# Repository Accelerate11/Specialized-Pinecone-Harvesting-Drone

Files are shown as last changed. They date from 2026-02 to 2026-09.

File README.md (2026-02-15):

# Specialized-Pinecone-Harvesting-Drone

To address the issues of high safety risks and low efficiency associated with manual pinecone harvesting, as well as the significant damage and loss caused by vibratory harvesters, this project has developed an intelligent pinecone harvesting system that deeply integrates a UAV, a robotic arm, and a striking end-effector.

The system employs a coaxial oct-rotor platform to achieve maneuverable flight within forest environments. It establishes a pinecone recognition system for precise target positioning and proposes a path planning method that simultaneously considers attitude, position, and obstacles, ensuring a safe and efficient approach to the pinecones. Additionally, an integrated cooperative control dynamic model for the UAV and the robotic arm is established to enhance operational stability.

This system enables rapid identification, precise harvesting, and stable flight in complex forest environments. It effectively reduces labor costs, improves harvesting efficiency, minimizes fruit loss, alleviates labor intensity, mitigates operational risks, and contributes to the modernization of forestry.

This project selects the NVIDIA Jetson Orin Nano as the onboard computer, the CUAV X7 as the flight controller, the DJI Mid-360 as the LiDAR, the SIYI A8 mini as the gimbal camera, and an RGB-D Sensor Camera（https://wiki.dfrobot.com.cn/_SKU_SEN0583_RGB-D_Sensor_Camera） as the depth camera.

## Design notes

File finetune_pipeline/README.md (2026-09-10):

# LocateAnything 松果微调

供以后换入高质量 YOLO 数据集后复用。训练在 Win11 的 WSL2 `ld666` 中进行，不能直接拿 GGUF 训练。

## 固定环境

- Eagle：`/home/ld666/projects/Eagle`，commit `783f656d127ee498137b5ff52603ce36c292d317`
- Python 环境：`/home/ld666/venvs/locateanything`
- 完整基础模型：`/home/ld666/model-cache/LocateAnything-3B`
- 训练脚本：`/mnt/e/locate4b/finetune_pipeline/scripts/train_pinecone_lora.sh`
- checkpoint 建议放在：`/home/ld666/work_dirs/locateanything_pinecone/`

当前 Eagle 已应用 WSL/SDPA 兼容修改。若以后重新克隆 Eagle，在仓库根目录执行：

```bash
git apply --check /mnt/e/locate4b/finetune_pipeline/patches/eagle_wsl_sdpa.patch
git apply /mnt/e/locate4b/finetune_pipeline/patches/eagle_wsl_sdpa.patch
```

## 1. 准备数据

推荐新数据单独放置，不覆盖旧数据：

```text
E:\locate4b\dataset_hq\
  data.yaml
  images\train\
  images\val\
  labels\train\
  labels\val\
```

标注必须是 YOLO 检测格式：每行 `class x_center y_center width height`，坐标归一化到 0–1。训练前重点确认：所有可见松果尽量完整标注、框不越界、训练集和验证集不重复、空标注图片确实没有松果。

## 2. 转换为 ShareGPT JSONL

在 Windows PowerShell 中执行：

```powershell
python E:\locate4b\finetune_pipeline\scripts\convert_yolo_to_locateanything.py `
  --source E:\locate4b\dataset_hq `
  --output E:\locate4b\dataset_hq_true `
  --wsl-output-root /mnt/e/locate4b/dataset_hq_true
```

检查 `dataset_hq_true\conversion_report.json`，确认样本数、框数、类别和错误记录。训练使用自动生成的 `dataset_hq_true\recipe_train.json`。

## 3. 一步拉烟测试

每次换数据后必须先跑 1 步，确认数据、显存和保存流程正常：

```powershell
wsl.exe -d ld666 -- bash -lc 'META_PATH=/mnt/e/locate4b/dataset_hq_true/recipe_train.json OUTPUT_DIR=/home/ld666/work_dirs/locateanything_pinecone/smoke_hq MAX_STEPS=1 SAVE_STEPS=1 GRADIENT_ACC=1 bash /mnt/e/locate4b/finetune_pipeline/scripts/train_pinecone_lora.sh'
```

`OUTPUT_DIR` 必须使用新的空目录。

## 4. 正式微调

先跑 100 步小规模实验，不要在新数据上直接长时间训练：

```powershell
wsl.exe -d ld666 -- bash -lc 'META_PATH=/mnt/e/locate4b/dataset_hq_true/recipe_train.json OUTPUT_DIR=/home/ld666/work_dirs/locateanything_pinecone/lora_hq_v1 MAX_STEPS=100 SAVE_STEPS=50 bash /mnt/e/locate4b/finetune_pipeline/scripts/train_pinecone_lora.sh'
```

默认配置是 BF16、SDPA、LoRA rank 32、冻结视觉骨干和 MLP、上下文 4096。正式步数应根据新数据规模和验证结果决定，不要只看训练 loss。

## 5. 评估

基础模型和新 checkpoint 必须使用相同样本、相同 seed、相同 `slow` 解码分别评估：

```powershell
wsl.exe -d ld666 -- bash -lc 'source /home/ld666/venvs/locateanything/bin/activate && python /mnt/e/locate4b/finetune_pipeline/scripts/evaluate_pinecone.py --model /home/ld666/work_dirs/locateanything_pinecone/lora_hq_v1 --annotation /mnt/e/locate4b/dataset_hq_true/annotations/pinecone_val.jsonl --image-root /mnt/e/locate4b/dataset_hq_true/images --output /mnt/e/locate4b/results/eval_lora_hq_v1.json --limit 0 --seed 42 --generation-mode slow'
```

关注 Precision、Recall、F1、非法框数量和实际叠加图。只有验证集优于基础模型，才进入合并和部署转换。

## 6. 合并 LoRA

```powershell
wsl.exe -d ld666 -- bash -lc 'source /home/ld666/venvs/locateanything/bin/activate && python /mnt/e/locate4b/finetune_pipeline/scripts/merge_locateanything_lora.py --input /home/ld666/work_dirs/locateanything_pinecone/lora_hq_v1 --output /home/ld666/work_dirs/locateanything_pinecone/lora_hq_v1_merged'
```

输出目录必须为空。

## 7. 转为 GGUF 并量化

```bash
source /home/ld666/venvs/locateanything/bin/activate
mkdir -p /home/ld666/work_dirs/locateanything_pinecone/gguf_hq_v1

python /home/ld666/projects/llama.cpp-locateanything/convert_hf_to_gguf.py \
  /home/ld666/work_dirs/locateanything_pinecone/lora_hq_v1_merged \
  --outfile /home/ld666/work_dirs/locateanything_pinecone/gguf_hq_v1/LocateAnything-Pinecone-BF16.gguf \
  --outtype bf16

python /home/ld666/projects/llama.cpp-locateanything/convert_hf_to_gguf.py \
  /home/ld666/work_dirs/locateanything_pinecone/lora_hq_v1_merged \
  --outfile /home/ld666/work_dirs/locateanything_pinecone/gguf_hq_v1/LocateAnything-Pinecone-BF16.gguf \
  --outtype bf16 --mmproj

/home/ld666/projects/llama.cpp-locateanything/build/bin/llama-quantize \
  /home/ld666/work_dirs/locateanything_pinecone/gguf_hq_v1/LocateAnything-Pinecone-BF16.gguf \
  /home/ld666/work_dirs/locateanything_pinecone/gguf_hq_v1/LocateAnything-Pinecone-Q4_K_M.gguf \
  Q4_K_M
```

最后再用 `evaluate_gguf_pinecone.py` 对原始 Q4 和新 Q4 做同口径评估，通过后复制到 Jetson。

## 当前原型结果

固定 12 张低质量验证样本、llama.cpp Q4_K_M、`slow` 解码：原始模型 IoU@0.5 F1 为 0.7671，当前微调模型为 0.8010。该结果只证明流程可行，不能代替高质量数据上的重新评估。

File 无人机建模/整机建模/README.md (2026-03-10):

此文件夹用于储存整机建模，使用STEP格式
一代机建模比较粗糙，仅作了各个模块的大致位置与接合演示，一代机完成了实际飞行，使用多模块独立供电方式，以便于调试使用。

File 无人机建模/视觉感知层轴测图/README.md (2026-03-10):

视觉感知层包括视觉处理单元（1）、广角云台相机（2）、手眼相机（3）及激光雷达（4）。所述系统通过广角云台相机与手眼相机的双阶段协同检测获取多尺度视觉信息及环境深度信息，利用视觉处理单元进行数据处理与控制决策，并通过综合视觉控制模块实现松果目标的远距离先验引导识别与近距离成熟度辨识及打击定位，完成林间环境下的松果精准识别与采摘作业引导过程。

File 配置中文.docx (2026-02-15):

配置系统语言为中文

sudo apt install language-pack-zh-hans language-pack-gnome-zh-hans

安装完成后，再运行：

sudo update-locale LANG=zh_CN.UTF-8

然后reboot，系统语言应该就是中文了

配置中文拼音输入法

https://cloud.tencent.com/developer/article/2156923

首先

sudo apt-get update

sudo apt-get install fcitx-bin

sudo apt-get install fcitx-table

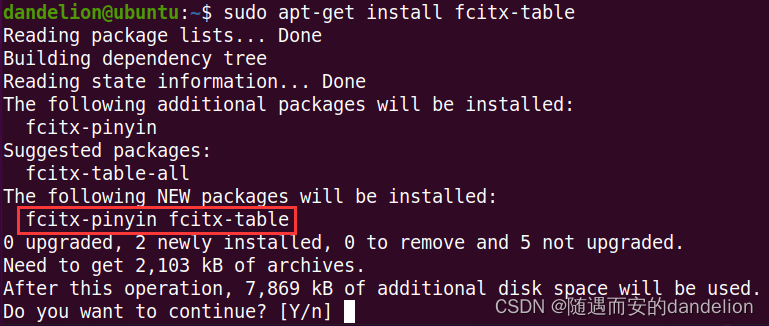
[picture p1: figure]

1、添加中文语言支持

打开 系统设置——区域和语言——管理已安装的语言——在“语言”tab下——点击“添加或删除语言”

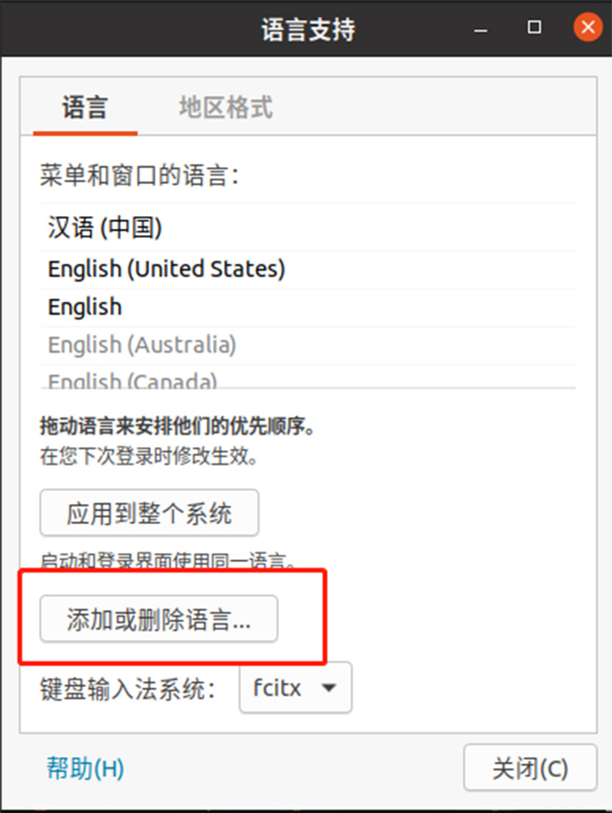
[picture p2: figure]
打开 系统设置——区域和语言——管理已安装的语言——在“语言”tab下——点击“添加或删除语言”

弹出“已安装语言”窗口，勾选中文（简体），点击应用

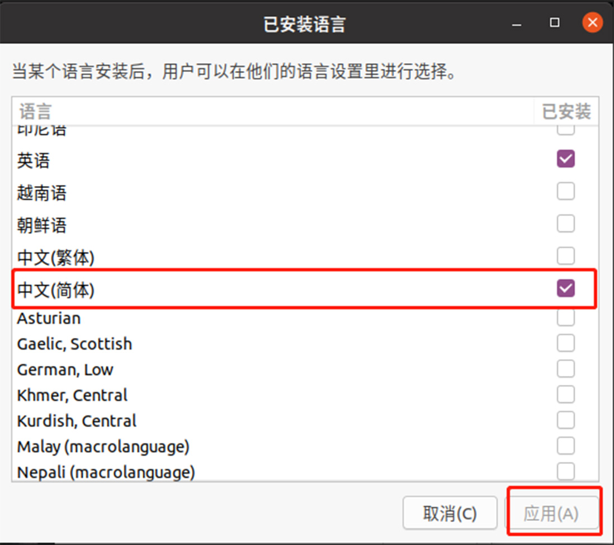
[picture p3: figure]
弹出“已安装语言”窗口，勾选中文（简体），点击应用

回到“语言支持”窗口，在键盘输入法系统中，选择“fcitx”

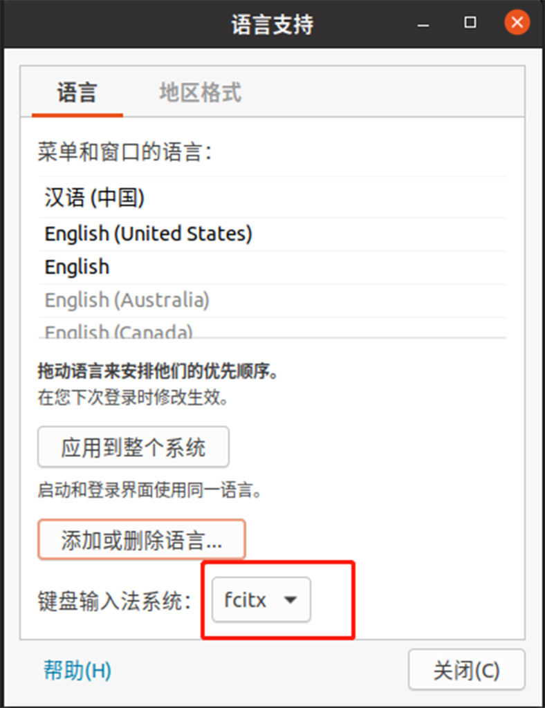
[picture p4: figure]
回到“语言支持”窗口，在键盘输入法系统中，选择“fcitx”

点击“应用到整个系统”，关闭窗口，reboot

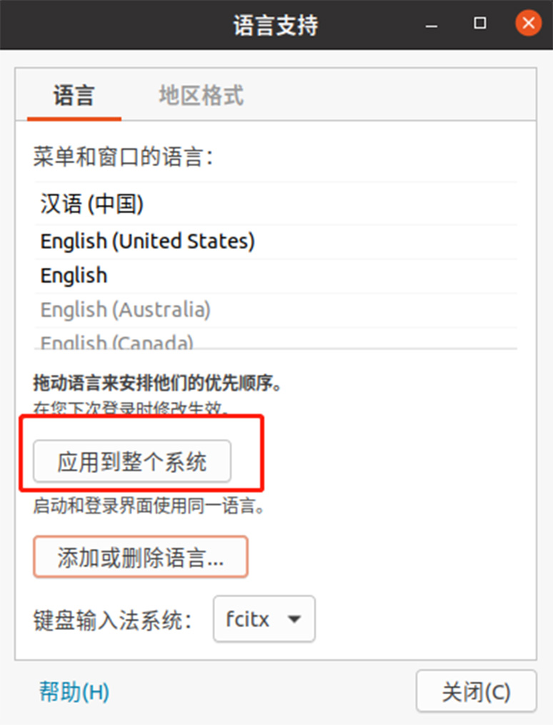
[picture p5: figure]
如果在键盘输入法系统中，没有“fcitx”选项时，建议先打开终端手动安装fcitx：sudo apt-get install fcitx等安装成功之后再执行上述步骤点击“应用到整个系统”，关闭窗口，重启电脑
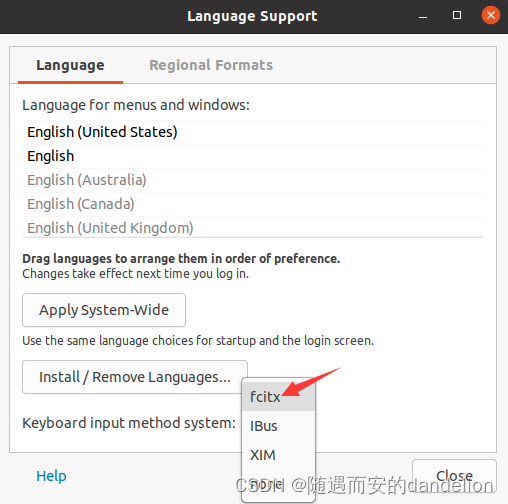
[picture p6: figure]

选择输入法框架fcitx，然后单击Close，重启系统。单击Ubuntu右上角的小键盘图标，在下拉菜单里选择Configure Current Input Method，可以看到已经安装的两个拼音输入法：

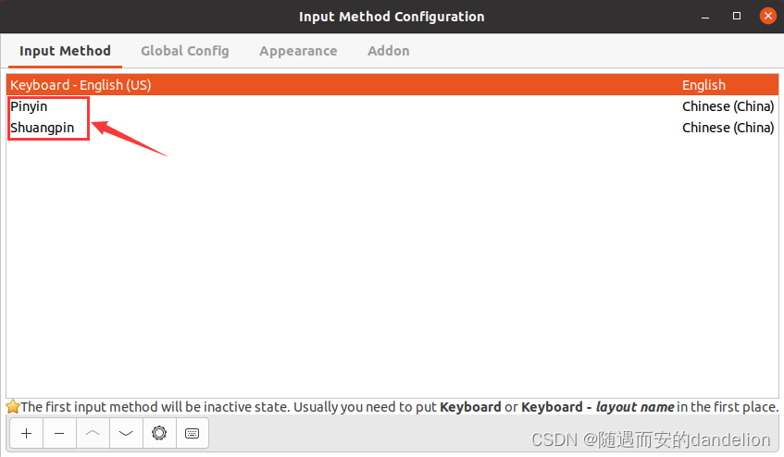
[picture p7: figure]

打开一个终端或者文本编辑器，按“CTRL+空格”键，在中文/英文输入法之间切换；按“CTRL+SHIFT”键，在fcitx框架中的多种中文输入法之间切换。

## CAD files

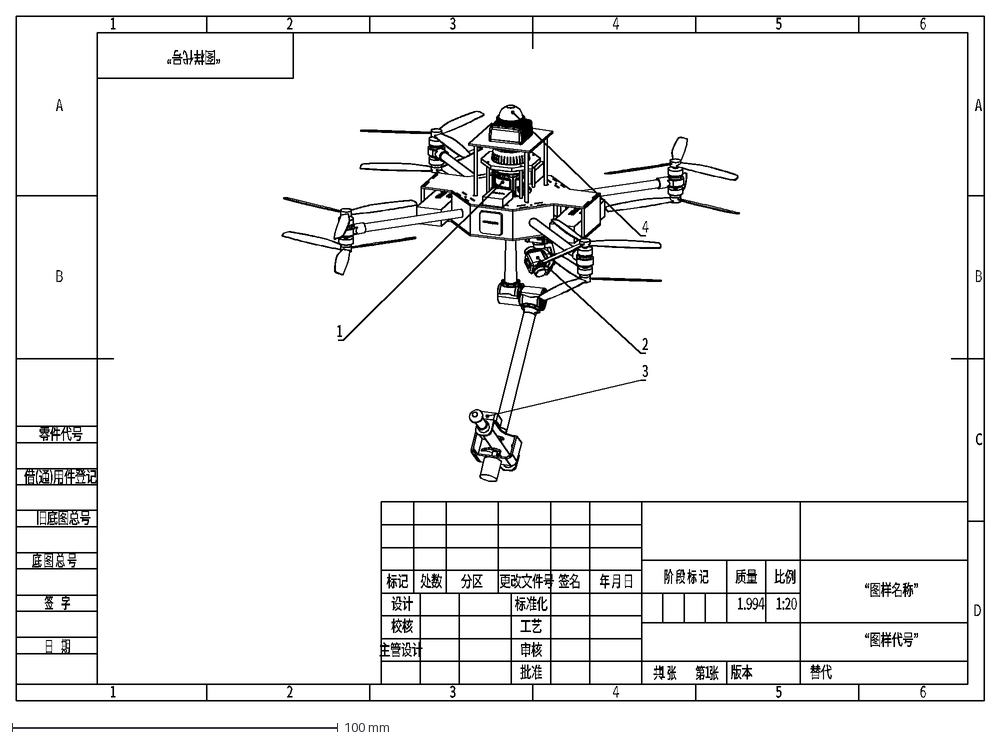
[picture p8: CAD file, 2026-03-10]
无人机建模/视觉感知层轴测图/Pick_Pinecone_Super.DXF
“图样代号”
替代
版本
审核
工艺
比例
质量
第 张
共 张
阶 段 标 记
批准
标准化
主管设计
年 月 日
签名
更改文件号
分区
处数
标记
设计
校核
零件代号
借(通)用件登记
旧底图总号
底 图 总 号
日 期
“图样名称”
1.994
1
1:20
B
A
D
C
签 字
2
5
4
3
6

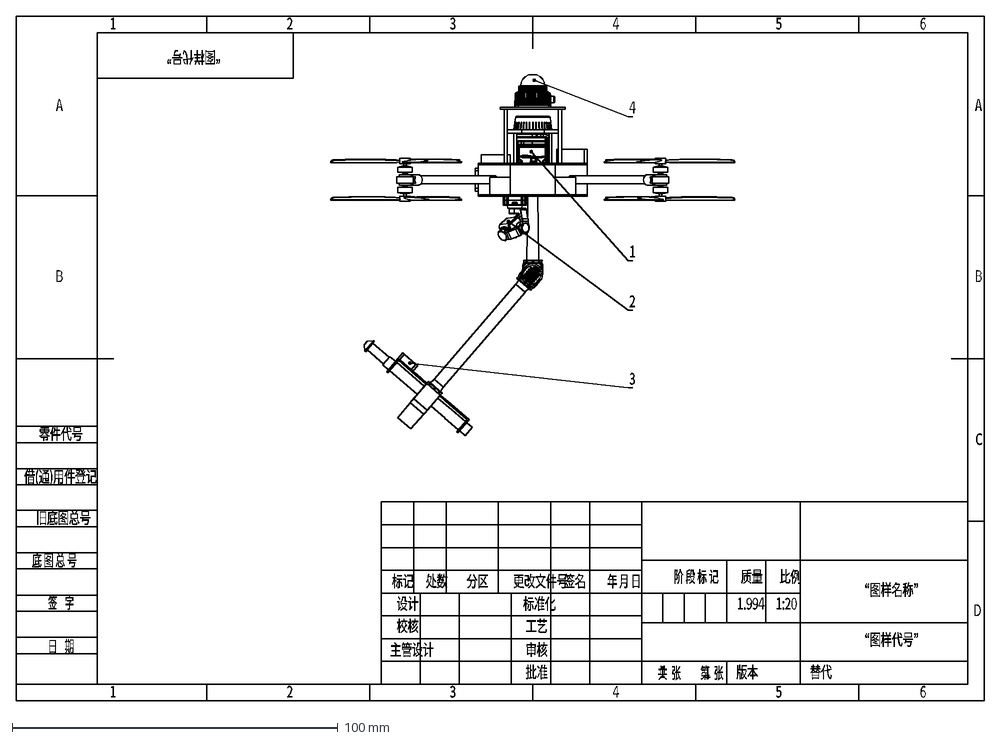
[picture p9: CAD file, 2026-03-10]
无人机建模/视觉感知层轴测图/Pick_Pinecone_Right.DXF
“图样代号”
替代
版本
审核
工艺
比例
质量
第 张
共 张
阶 段 标 记
批准
标准化
主管设计
年 月 日
签名
更改文件号
分区
处数
标记
设计
校核
零件代号
借(通)用件登记
旧底图总号
底 图 总 号
日 期
“图样名称”
1.994
1
1:20
B
A
D
C
签 字
2
5
4
3
6

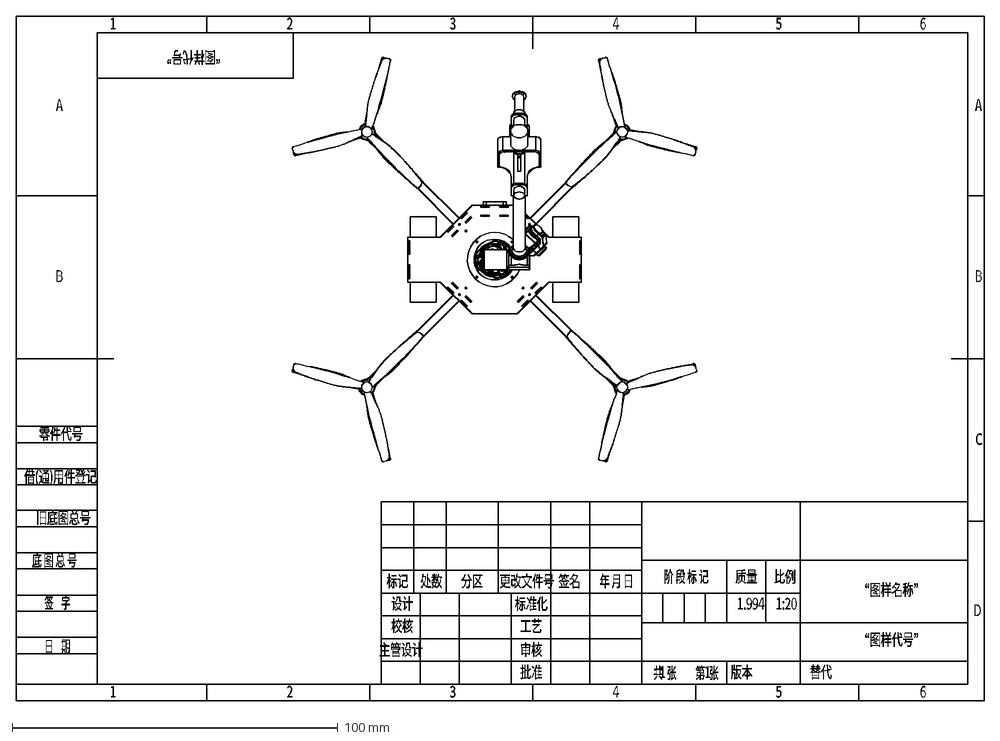
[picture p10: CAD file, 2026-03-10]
无人机建模/视觉感知层轴测图/Pick_Pinecone_Bottom.DXF
“图样代号”
替代
版本
审核
工艺
比例
质量
第 张
共 张
阶 段 标 记
批准
标准化
主管设计
年 月 日
签名
更改文件号
分区
处数
标记
设计
校核
零件代号
借(通)用件登记
旧底图总号
底 图 总 号
日 期
“图样名称”
1.994
1
1:20
B
A
D
C
签 字
2
5
4
3
6

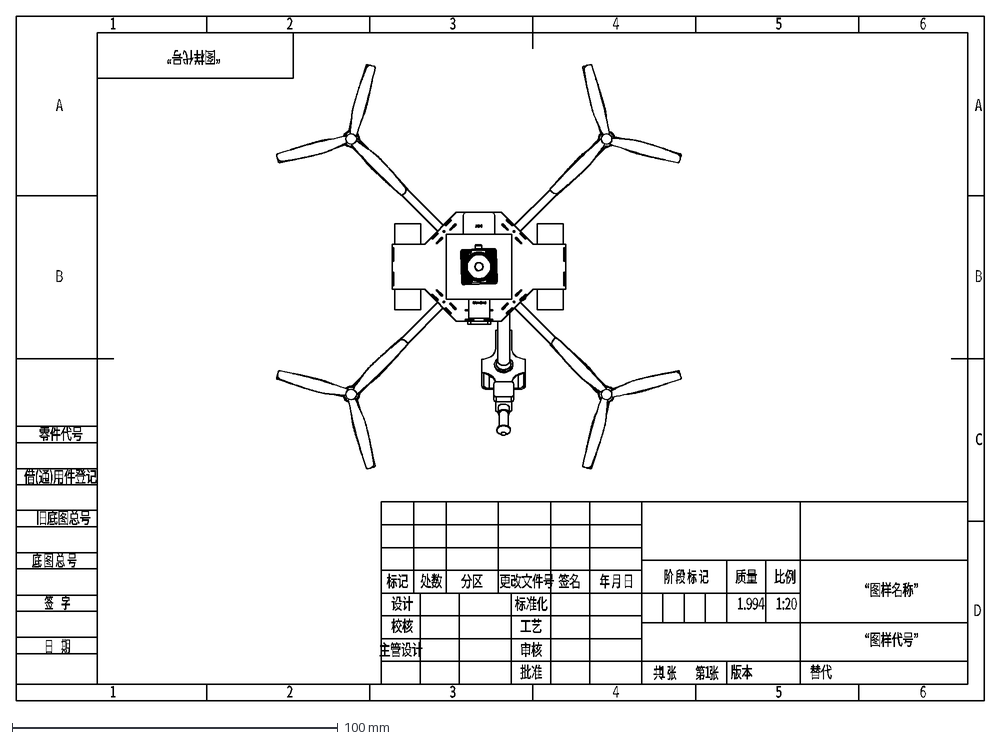
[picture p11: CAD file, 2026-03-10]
无人机建模/视觉感知层轴测图/Pick_Pinecone_Plan.DXF
“图样代号”
替代
版本
审核
工艺
比例
质量
第 张
共 张
阶 段 标 记
批准
标准化
主管设计
年 月 日
签名
更改文件号
分区
处数
标记
设计
校核
零件代号
借(通)用件登记
旧底图总号
底 图 总 号
日 期
“图样名称”
1.994
1
1:20
B
A
D
C
签 字
2
5
4
3
6

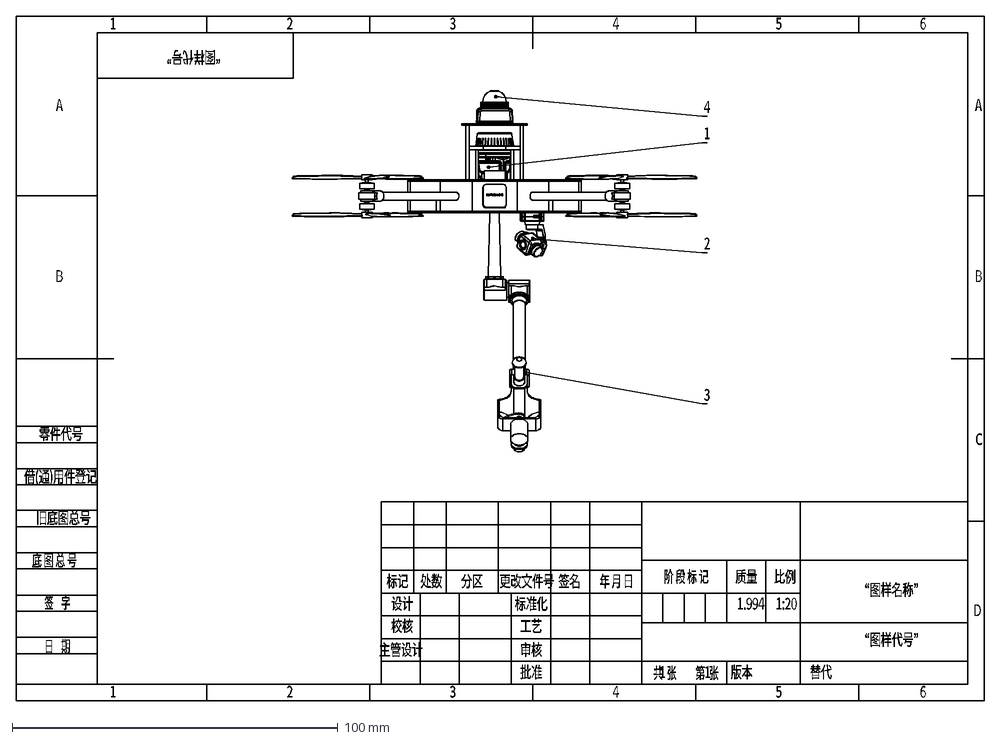
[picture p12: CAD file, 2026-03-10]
无人机建模/视觉感知层轴测图/Pick_Pinecone_Front.DXF
“图样代号”
替代
版本
审核
工艺
比例
质量
第 张
共 张
阶 段 标 记
批准
标准化
主管设计
年 月 日
签名
更改文件号
分区
处数
标记
设计
校核
零件代号
借(通)用件登记
旧底图总号
底 图 总 号
日 期
“图样名称”
1.994
1
1:20
B
A
D
C
签 字
2
5
4
3
6

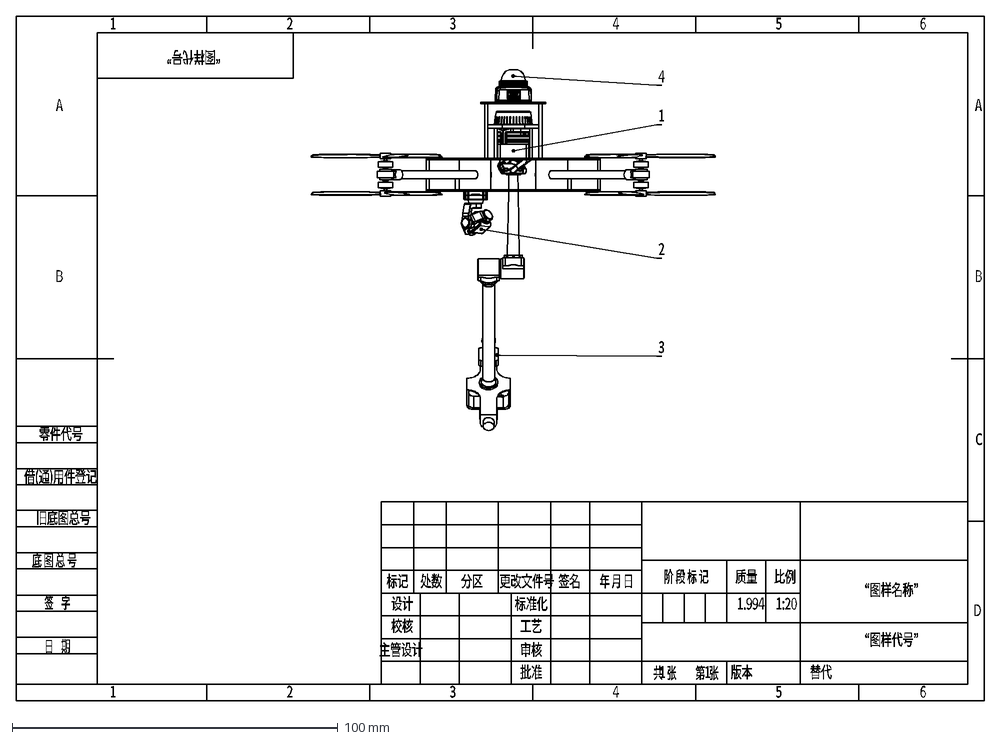
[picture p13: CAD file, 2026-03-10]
无人机建模/视觉感知层轴测图/Pick_Pinecone_Back.DXF
“图样代号”
替代
版本
审核
工艺
比例
质量
第 张
共 张
阶 段 标 记
批准
标准化
主管设计
年 月 日
签名
更改文件号
分区
处数
标记
设计
校核
零件代号
借(通)用件登记
旧底图总号
底 图 总 号
日 期
“图样名称”
1.994
1
1:20
B
A
D
C
签 字
2
5
4
3
6

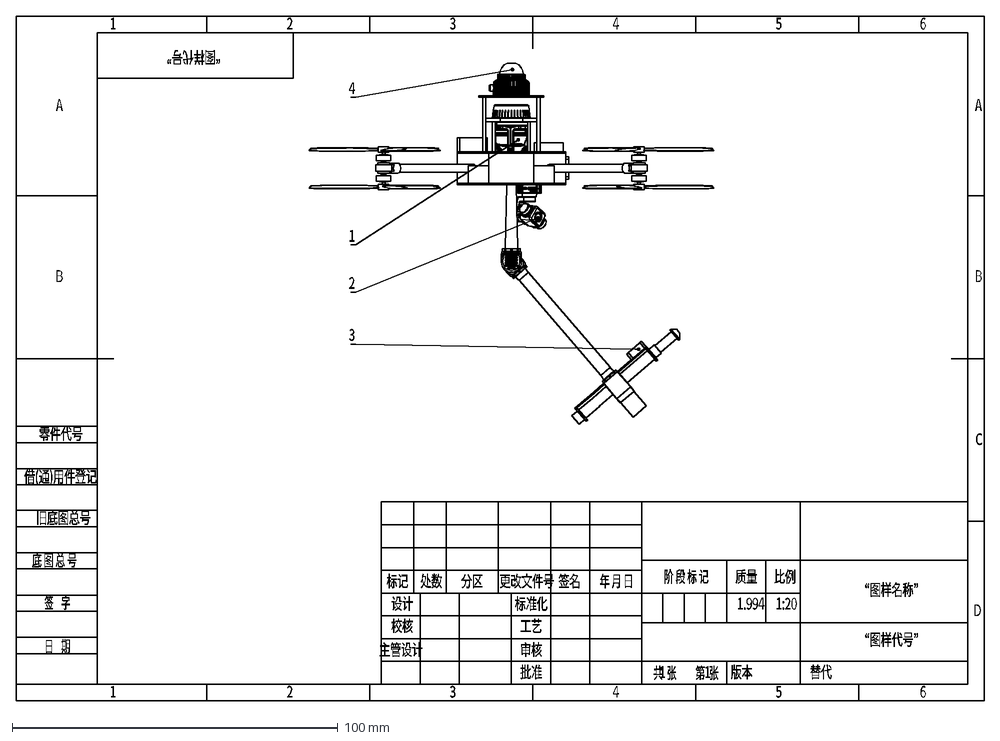
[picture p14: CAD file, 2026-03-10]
无人机建模/视觉感知层轴测图/Pick_Pinecone_Left.DXF
“图样代号”
替代
版本
审核
工艺
比例
质量
第 张
共 张
阶 段 标 记
批准
标准化
主管设计
年 月 日
签名
更改文件号
分区
处数
标记
设计
校核
零件代号
借(通)用件登记
旧底图总号
底 图 总 号
日 期
“图样名称”
1.994
1
1:20
B
A
D
C
签 字
2
5
4
3
6

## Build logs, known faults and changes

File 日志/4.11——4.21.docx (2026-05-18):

如果想实现torch模型实时推理相机视频流，请先去看配置torch的教程

建议在虚拟环境里进行以下教程，因为安装了很多包，怕污染主环境

1. 硬件连接

网线直连：用A8 mini附带的JST-GH转RJ45线连接相机，RJ45端插入Jetson Orin Nano的网口。

独立供电：用电源线给A8 mini供电（11-25.2V，3-6S电池）。同时给Jetson Orin Nano通电。

2. 软件配置

修改Jetson网络：需要将Jetson的IP设为和A8 mini同一网段，因为A8 mini出厂默认IP是192.168.144.25。

图形界面：在Ubuntu设置里为有线连接手动配置一个IP，比如192.168.144.100。

验证连接：

首先安装arp-scan

bash

sudo apt update && sudo apt install arp-scan -y

然后用arp-scan扫描当前子网，看看相机是否正常工作以及相机的IP

bash

sudo arp-scan --interface=enP8p1s0 192.168.144.0/24

预期输出

Interface: enP8p1s0, type: EN10MB, MAC: 3c:6d:66:be:bb:88, IPv4: 192.168.144.100

Starting arp-scan 1.9.7 with 256 hosts (https://github.com/royhills/arp-scan) 192.168.144.25 7c:d1:37:a8:20:22 (Unknown)

1 packets received by filter, 0 packets dropped by kernel

Ending arp-scan 1.9.7: 256 hosts scanned in 2.042 seconds (125.37 hosts/sec). 1 responded

黄色部分证明相机IP确实是192.168.144.25

获取视频流：A8 mini默认通过RTSP协议输出视频流。

先检查 RTSP 端口是否开放

bash

sudo apt install nmap -y

nmap -p 8554 192.168.144.25

预期输出

bash

Starting Nmap 7.80 ( https://nmap.org ) at 2026-04-20 21:47 CST

Nmap scan report for 192.168.144.25

Host is up (0.00037s latency).

PORT STATE SERVICE

8554/tcp open rtsp-alt

Nmap done: 1 IP address (1 host up) scanned in 0.06 seconds

使用 ffplay 测试相机是否能输出视频流

bash

sudo apt install ffmpeg -y

ffplay rtsp://192.168.144.25:8554/main.264 -fflags nobuffer -flags low_delay -framedrop

预期会输出相机实施拍摄的画面

3 python脚本（OpemCV+FFmpeg）（减少视频采集缓冲区+异步双线程 （Pipeline）降低延迟）

创建python脚本drone_inference.py

python

import cv2

import torch

import time

import argparse

import os

import threading

import queue

from pathlib import Path

from ultralytics import YOLO

class LowLatencyYOLOPipeline:

def __init__(self, model_path, video_source, width=640, height=480, fps=30):

# 优化 RTSP 传输参数：TCP、低延迟标志、减小缓冲

os.environ['OPENCV_FFMPEG_CAPTURE_OPTIONS'] = (

'rtsp_transport;tcp|max_delay;100000|buffer_size;512000|flags;low_delay'

)

# 加载模型（建议使用 TensorRT 引擎文件 .engine 以获得最低延迟）

self.model = self.load_model(model_path)

self.video_source = video_source

self.use_rtsp = isinstance(video_source, str) and video_source.startswith('rtsp://')

self.width = width

self.height = height

self.fps = fps

# 打开视频源并设置缓冲区大小为 1（关键优化）

self.cap = self._open_capture()

if not self.cap.isOpened():

raise RuntimeError(f"无法打开视频源: {video_source}")

# 读取实际参数

self.frame_width = int(self.cap.get(cv2.CAP_PROP_FRAME_WIDTH))

self.frame_height = int(self.cap.get(cv2.CAP_PROP_FRAME_HEIGHT))

self.frame_fps = self.cap.get(cv2.CAP_PROP_FPS)

print(f"视频源已开启: {self.frame_width}x{self.frame_height} @ {self.frame_fps:.2f}fps")

print(f"模型加载成功: {Path(model_path).name}")

# 异步队列：最多缓存 2 帧，丢弃旧帧以保持最低延迟

self.frame_queue = queue.Queue(maxsize=2)

self.running = True

self.reader_thread = threading.Thread(target=self._reader_worker, daemon=True)

def _open_capture(self):

"""打开视频捕获设备，强制设置缓冲区大小为 1"""

if isinstance(self.video_source, int) or (isinstance(self.video_source, str) and self.video_source.isdigit()):

source = int(self.video_source)

cap = cv2.VideoCapture(source, cv2.CAP_V4L2)

cap.set(cv2.CAP_PROP_FRAME_WIDTH, self.width)

cap.set(cv2.CAP_PROP_FRAME_HEIGHT, self.height)

cap.set(cv2.CAP_PROP_FPS, self.fps)

else:

# RTSP 或视频文件，强制使用 FFMPEG

cap = cv2.VideoCapture(self.video_source, cv2.CAP_FFMPEG)

# 关键：将缓冲区大小设为 1，避免 OpenCV 内部缓存多帧引入延迟

cap.set(cv2.CAP_PROP_BUFFERSIZE, 1)

return cap

def load_model(self, model_path):

model = YOLO(model_path)

if torch.cuda.is_available():

model.to('cuda')

return model

def _reader_worker(self):

"""生产者线程：持续读取帧，只保留最新的一帧"""

reconnect_attempts = 0

while self.running:

ret, frame = self.cap.read()

if not ret:

print("读取帧失败，尝试重新连接...")

self.cap.release()

time.sleep(1)

# 重新打开

try:

self.cap = self._open_capture()

if self.cap.isOpened():

reconnect_attempts = 0

print("重连成功")

continue

except Exception as e:

print(f"重连异常: {e}")

reconnect_attempts += 1

if reconnect_attempts > 5:

print("重连失败超过5次，退出程序")

self.running = False

break

continue

reconnect_attempts = 0 # 成功读取后重置计数

# 队列若已满，则丢弃最旧的帧（保持最新帧）

if self.frame_queue.full():

try:

self.frame_queue.get_nowait()

except queue.Empty:

pass

self.frame_queue.put(frame)

def infer_frame(self, frame):

results = self.model(frame, verbose=False)

result = results[0]

infer_time = result.speed['inference'] / 1000.0

return result, infer_time

def draw_results(self, frame, result, infer_time):

if result.boxes is not None:

for box in result.boxes:

x1, y1, x2, y2 = map(int, box.xyxy[0].tolist())

conf = float(box.conf[0])

cls_id = int(box.cls[0])

label = f"{result.names[cls_id]} {conf:.2f}"

cv2.rectangle(frame, (x1, y1), (x2, y2), (0, 255, 0), 2)

cv2.putText(frame, label, (x1, y1-10),

cv2.FONT_HERSHEY_SIMPLEX, 0.5, (0, 255, 0), 2)

fps_text = f"FPS: {1/infer_time:.1f}" if infer_time > 0 else "FPS: --"

cv2.putText(frame, fps_text, (10, 30),

cv2.FONT_HERSHEY_SIMPLEX, 1, (0, 0, 255), 2)

cv2.putText(frame, f"Infer: {infer_time*1000:.1f}ms", (10, 60),

cv2.FONT_HERSHEY_SIMPLEX, 0.7, (0, 0, 255), 2)

return frame

def run(self):

"""消费者主线程：从队列获取最新帧，进行推理并显示"""

self.reader_thread.start()

print("开始推理（低延迟模式），按 'q' 键退出...")

while self.running:

try:

# 等待新帧，超时 1 秒

frame = self.frame_queue.get(timeout=1.0)

except queue.Empty:

if not self.running:

break

continue

# 推理与绘制

result, infer_time = self.infer_frame(frame)

display_frame = self.draw_results(frame.copy(), result, infer_time)

cv2.imshow('YOLO Detection (Low Latency)', display_frame)

# 按 'q' 退出

if cv2.waitKey(1) & 0xFF == ord('q'):

self.running = False

break

# 清理资源

self.running = False

self.reader_thread.join(timeout=1.0)

self.cap.release()

cv2.destroyAllWindows()

def main():

parser = argparse.ArgumentParser(description="YOLO 推理管道")

parser.add_argument('--model', type=str, required=True, help='模型路径 (.pt 或 .engine)')

parser.add_argument('--source', type=str, default='0', help='视频源：摄像头ID、RTSP地址或视频文件')

parser.add_argument('--width', type=int, default=640, help='采集宽度')

parser.add_argument('--height', type=int, default=480, help='采集高度')

parser.add_argument('--fps', type=int, default=30, help='采集帧率')

args = parser.parse_args()

if not Path(args.model).exists():

print(f"错误：模型文件不存在 {args.model}")

return

pipeline = LowLatencyYOLOPipeline(

model_path=args.model,

video_source=args.source,

width=args.width,

height=args.height,

fps=args.fps

)

try:

pipeline.run()

except KeyboardInterrupt:

print("\n程序被用户中断")

except Exception as e:

print(f"运行时错误: {e}")

if __name__ == "__main__":

main()

运行脚本

bash

python drone_inference.py --model /home/nvidia/CAMERA/best.pt --source "rtsp://192.168.144.25:8554/main.264"

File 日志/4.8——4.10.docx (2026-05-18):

零.准备

ros2 版本 humble

给雷达供电接入电脑，设置静态ip(不要远程,建议直连)

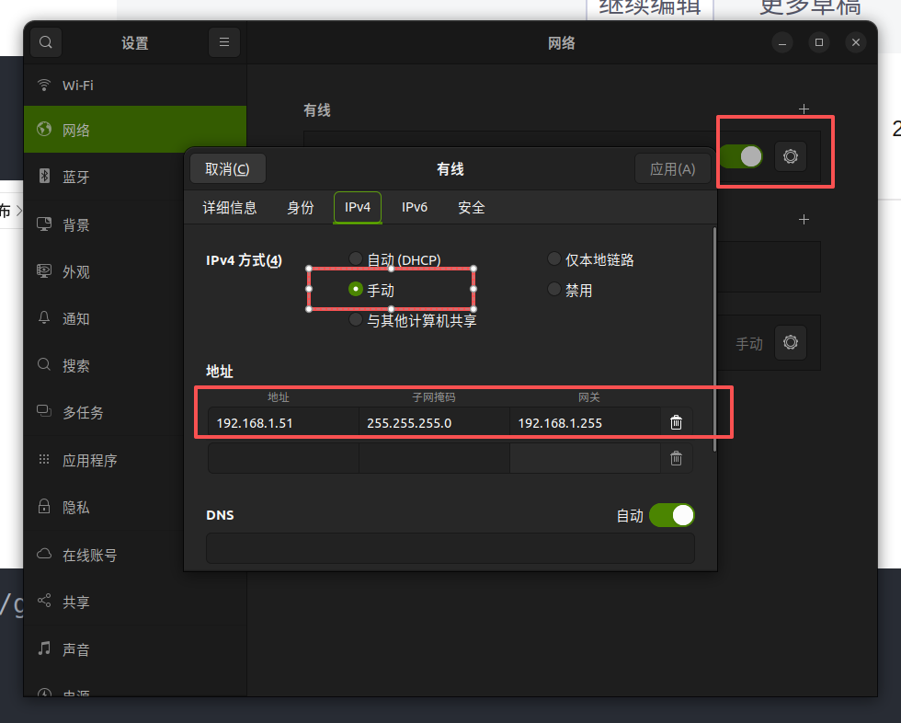
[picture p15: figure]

上述配置的IP地址是自己电脑的IP地址（记住！后面要用到）

1． sdk2

bash

git clone https://github.com/Livox-SDK/Livox-SDK2.git

cd ./Livox-SDK2/

mkdir build

cd build

cmake .. && make

sudo make install

如果linux翻墙困难的话，可以先在个人windos笔记本上通过github加速器去https://github.com/Livox-SDK/Livox-SDK2.git网址下载Livox-SDK2包（注意从网站上下载下来的源代码包自动带-master后缀，并不是你下载错了，把后缀删除了以后接着照此教程走）

2． livox_ros_driver2

bash

git clone https://github.com/Livox-SDK/livox_ros_driver2.git ws_livox/src/livox_ros_driver2

如果linux翻墙困难的话，可以先在个人windos笔记本上通过github加速器去 https://github.com/Livox-SDK/livox_ros_driver2.git网址下载Livox-ros-driver2包（注意从网站上下载下来的源代码包自动带-master后缀，并不是你下载错了，把后缀删除了以后接着照此教程走），然后创建一个名为ws_livox的文件夹，再在其中创建一个名为src的文件夹，再把源代码包放进src里

cd ws_livox/src/livox_ros_driver2

pip3 install lark

./build.sh humble

3． 修改/ws_livox/src/livox_ros_driver2/config/MID360 配置文件

参考如下

{

"lidar_summary_info" : {

"lidar_type": 8

},

"MID360": {

"lidar_net_info" : {

"cmd_data_port": 56100,

"push_msg_port": 56200,

"point_data_port": 56300,

"imu_data_port": 56400,

"log_data_port": 56500

},

"host_net_info" : {

"cmd_data_ip" : "192.168.1.51",

"cmd_data_port": 56101,

"push_msg_ip": "192.168.1.51",

"push_msg_port": 56201,

"point_data_ip": "192.168.1.51",

"point_data_port": 56301,

"imu_data_ip" : "192.168.1.51",

"imu_data_port": 56401,

"log_data_ip" : "",

"log_data_port": 56501

}

},

"lidar_configs" : [

{

"ip" : "192.168.1.141",

"pcl_data_type" : 1,

"pattern_mode" : 0,

"extrinsic_parameter" : {

"roll": 0.0,

"pitch": 0.0,

"yaw": 0.0,

"x": 0,

"y": 0,

"z": 0

}

}

]

}

上述配置文件中黄色的部分是“零.准备”中你给自己电脑配置的IP地址，红色的部分是你的激光雷达的IP地址。雷达的ip地址为192.168.1.1xx,其中的xx是贴在雷达上面的SN码的最后两位数我的是41，所以ip为192.168.1.141

四．修改动态链接库 路径

错误信息： [livox_ros_driver2_node-1] 抛出 "class_loader::LibraryLoadException" 异常 [livox_ros_driver2_node-1] 具体错误：无法加载库 dlopen 错误：liblivox_lidar_sdk_shared.so - 无法打开共享对象文件（文件不存在），位于 ./src/shared_library.c:99

bash

find ~ -name "liblivox_lidar_sdk_shared.so" 2>/dev/null

运行以上命令行找到 Livox SDK 安装位置，请确保将 SDK 文件 liblivox_lidar_sdk_shared.so 手动复制到 ~/ws_livox/install/livox_ros_driver2/lib 目录下，否则运行时会报错

五．通过rviz2查看点云

把激光雷达和你的机载电脑连接好

bash

cd ./ws_livox

colcon build

source install/setup.bash

ros2 launch livox_ros_driver2 rviz_MID360_launch.py

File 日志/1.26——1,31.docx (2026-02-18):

1.26——1.31工作总结

这一周围绕第一次真机飞行任务做了一部分适配工作，主要是写了一个云台相机录视频的脚本和一个开机自启脚本（失败）；同时，本文档补充了一些云台相机的配置说明。

云台相机供电这回使用了诱骗头，诱骗头的供电支持多种输出，方便与激光雷达和云台相机的本地调试，电压调整调整如下（后续发现诱骗头供电不稳定，上机建议使用3S航电）：

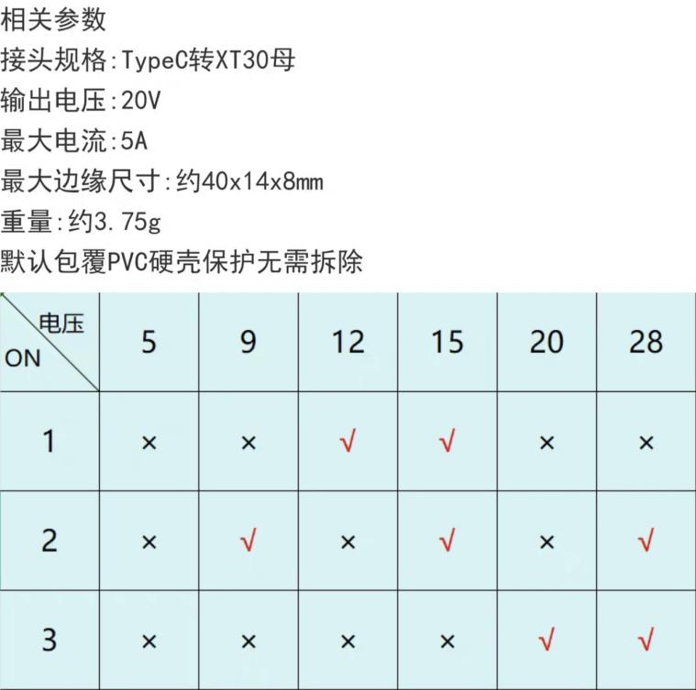
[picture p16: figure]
75cd4e96f1f75625d4e268d5966cb9c5

云台相机配置（网关配置与自检）：

1、配置Jetson OrinNano的网络

A8 mini默认IP为192.168.144.25,子网掩码255.255.255.0 (文档第4.4节)在终端中执行:

#设置静态IP(以eth0为例，请根据实际接口名称调整)

sudo ip addr add 192.168.144.30/24 dev ethe0

测试网络连通性：

ping 192.168.144.25

2、 视频流获取

安装依赖：

#安装FFmpeg

sudo apt update

sudo apt install ffmpeg

3、获取RTSP视频流

A8 mini的RTSP地址为:rtsp://192.168.144.25:8554/main.264 (文档第4.4节)

ffmpeg -i rtsp://192.168.144.25:8554/main.264 -f null -

3、 使用FFplay检查视频流是否正常：

FFplay是FFmpeg项目自带的轻量级播放器，兼容性极好。

ffplay -rtsp_transport tcp -i rtsp://192.168.144.25:8554/main.264

已经将以上步骤都集成到视频录制脚本里了

补充：清除某个旧接口的ip设置：

清空接口上的所有IP地址

此命令会移除指定接口上的所有IPv4地址。

sudo ip addr flush dev ethe

视频录制脚本部分（整理成txt放在了记录中）：

脚本源码：

!/bin/bash

# 自动网络配置与视频录制脚本

# 配置参数

CAMERA_IP="192.168.144.25" # A8 mini默认IP（文档第4.9节）

JETSON_IP="192.168.144.30" # Jetson静态IP（与相机同网段）

INTERFACE="eth0" # 网络接口名称，根据实际修改

RTSP_URL="rtsp://$CAMERA_IP:8554/main.264" # A8 mini默认RTSP地址（文档第4.4节）

OUTPUT_DIR="/home/nvidia/Videos" # 视频保存目录

# 生成带时间戳的文件名

FILENAME="a8mini_recording_$(date +%Y%m%d_%H%M%S).mp4"

OUTPUT_PATH="$OUTPUT_DIR/$FILENAME"

# 函数：记录日志

log() {

echo "[$(date '+%Y-%m-%d %H:%M:%S')] $1"

}

# 1. 检查网络接口是否存在

log "检查网络接口 $INTERFACE..."

if ! ip link show "$INTERFACE" &>/dev/null; then

log "错误: 接口 $INTERFACE 不存在。请检查接口名称（如 eth0、enp0s1）。"

exit 1

fi

# 2. 清除接口现有IP设置（避免冲突）

log "清除接口 $INTERFACE 的旧IP设置..."

sudo ip addr flush dev "$INTERFACE" 2>/dev/null

# 3. 设置静态IP

log "设置接口 $INTERFACE 的IP为 $JETSON_IP/24..."

sudo ip addr add "$JETSON_IP/24" dev "$INTERFACE"

if [ $? -ne 0 ]; then

log "警告: IP设置失败，可能已存在相同IP。尝试继续运行。"

fi

# 4. 启用接口

sudo ip link set dev "$INTERFACE" up

sleep 2 # 等待接口稳定

# 5. 验证网络连通性

log "检查相机连通性（ping $CAMERA_IP）..."

if ping -c 3 -W 3 "$CAMERA_IP" &>/dev/null; then

log "网络连通性正常。"

else

log "警告: 无法ping通相机。请检查相机供电、网线连接。"

# 不退出，尝试继续录制（可能相机需更长时间启动）

fi

# 6. 检查FFmpeg依赖

if ! command -v ffmpeg &>/dev/null; then

log "错误: FFmpeg未安装。正在尝试安装..."

sudo apt update && sudo apt install -y ffmpeg

if [ $? -ne 0 ]; then

log "错误: FFmpeg安装失败。请手动运行: sudo apt install ffmpeg"

exit 1

fi

fi

# 7. 开始录制视频

log "开始录制视频..."

log "相机RTSP流: $RTSP_URL"

log "输出文件: $OUTPUT_PATH"

log "按 Ctrl+C 停止录制。"

# 使用FFmpeg录制（-c copy 直接复制流，减少延迟）

ffmpeg -i "$RTSP_URL" -c copy -f mp4 -y "$OUTPUT_PATH"

ffmpeg_exit_code=$?

# 录制结束处理

if [ $ffmpeg_exit_code -eq 0 ]; then

log "录制已停止。视频已保存到: $OUTPUT_PATH"

elif [ $ffmpeg_exit_code -eq 255 ]; then

log "录制已被用户终止。视频已保存到: $OUTPUT_PATH"

# 检查文件是否存在且非空

if [ -s "$OUTPUT_PATH" ]; then

log "录制文件大小: $(du -h "$OUTPUT_PATH" | cut -f1)"

else

log "警告: 录制文件为空或不存在。"

fi

else

log "录制过程异常 (退出码: $ffmpeg_exit_code)。"

if [ -f "$OUTPUT_PATH" ]; then

if [ -s "$OUTPUT_PATH" ]; then

log "警告: 录制文件已保存但可能有损坏: $OUTPUT_PATH"

log "文件大小: $(du -h "$OUTPUT_PATH" | cut -f1)"

else

log "错误: 录制文件为空，正在删除..."

rm -f "$OUTPUT_PATH"

fi

fi

fi

exit $ffmpeg_exit_code

1.28同师姐去外场实际组装和测试：

云台相机测试，图像存在明显抖动，总结于云台自稳算法没有接通，并且由于我的失误未加隔振球，后续与机械臂统一再次进行测试。

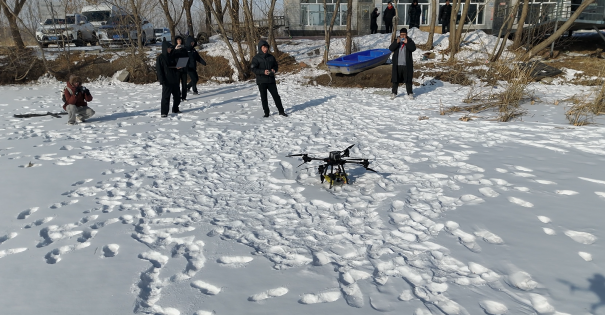
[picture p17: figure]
d642943bc4f91571ced9d0287a44630c
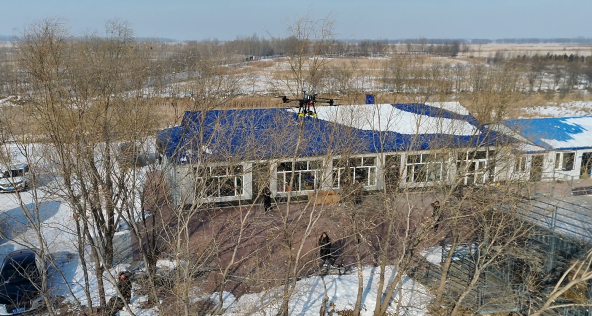
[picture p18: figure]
bdd4ffb2bf9d6f151b920efd8eb6baec
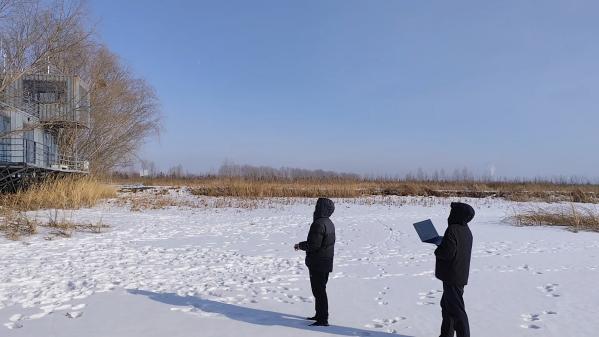
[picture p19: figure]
dfa6a3fa1fb112ef86c58c80fc97387f
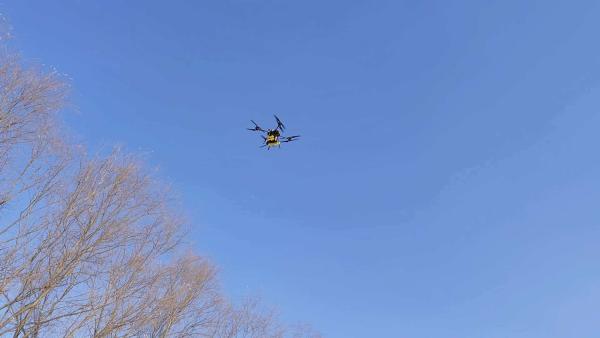
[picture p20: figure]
e085a764ea276d30c0e219d0dfdc6455

事后来到TIB与杨老师对接视觉识别算法部分，决定围绕深度相机展开视觉模型的开发；与德波学长对接过后买了两块雷巡X7+旨在给机械臂和云台各一个用来调试。固件最终确定为基于PX4。

这个周期先这样算一个小结，后续我们这边会针对飞控展开一些硬件学习和工作，主要是针对无人机的一些gazebo仿真和云台自稳的调试，明天开始本科组里面要开始美赛和离校，年前我们会分一次硬件，各个部分给相应的人去调试。

机械臂部分稳步推进，主要由倬一与王旭学长对接与调试。

本子部分馨纯参与度接近100%，主要是写挑战杯的本子，并且馨纯在视觉部分有一定的突破，等馨纯和大家返校后，会进行一次集中部署。

各个硬件尺寸和接口正在整理，很快会出。

降压模块交给李昕阳。

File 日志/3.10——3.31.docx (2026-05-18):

开学过后报名了挑战杯和国创赛，校赛都没有通过，项目目前还是存在一些问题，主要是学术产出比较少，项目商业企划不成体系，再打磨一年再去报名。

寒假期间写的专利都进入到了审核阶段。

技术层面，利用杨老师写的代码完成了YOLO数据集产出，张泽晰成功配置了基于Jetpack6.2的GPU版本pytorch环境配置并留存了详细的技术文档，清明之前可以开启视觉模型的训练。

另一方面基金会的资金到账，项目资金比较充足。

好长时间没写日志了，今天写一点吧

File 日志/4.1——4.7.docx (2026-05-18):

松果采摘机械臂由两组关节电机和两根长约为0.5m的臂杆组成，通过电机驱动二连杆将机械臂末端送至松果处进行击打。机械臂在无人机上搭载意味着需要对机械臂的震颤进行强有力的控制。而机械臂震颤来自于驱动时关节电机由于环境改变、控制指令改变、信号噪声等多种因素导致的力矩输出大幅度反复变化产生的反作用力，为了去除机械臂的震颤，本质上是要对机械臂进行柔顺控制，不能产生过大的加速度。当前阶段使用重力补偿+PID算法+滤波算法对机械臂进行柔顺控制。重力补偿是通过二连杆间的几何关系计算力矩来实时抵消机械臂运动时较明显的重力矩变化。PID算法是通过实时误差不断修正当前运动状态以达到目标运动状态，其部分代码如图所示：

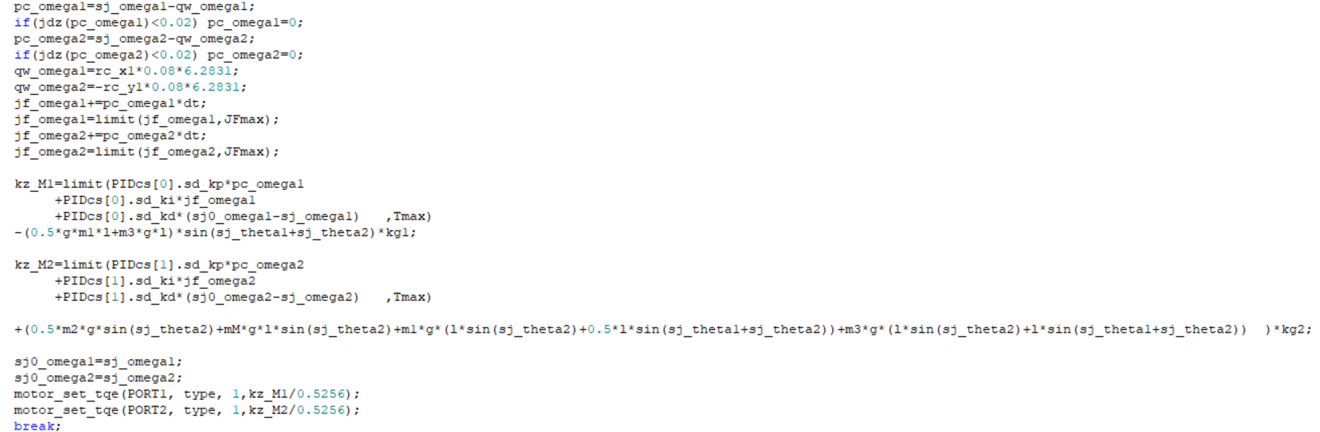
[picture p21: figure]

代码思路为：首先通过motor_get_state_send函数从电机处获取电机当前的位置（圈）、速度（圈/s）、力矩（N/m），根据电机当前位置与前一采样周期的位置之差获取电机速度，最后用电机速度结合PD参数与重力补偿控制输出力矩达到目标控制。

在程序实现过程中存在很多噪声，使得上述代码在运行时存在严重震颤。震颤产生的主要原因有：对位置进行差分时，采样周期为0.001s，电机位置的微小噪声即可产生角速度的巨大震荡，进而显著影响力矩值；电机本身读取信息时存在噪声的干扰，初始的位置信号具有一定的波动。因此滤波在此程序中十分重要，在调试过程中使用JScope可以实时观测各变量的值，相当于一台示波器，能够大大方便调试。滤波前期望速度与实际速度间的关系如图（蓝色为期望，红色为实际）

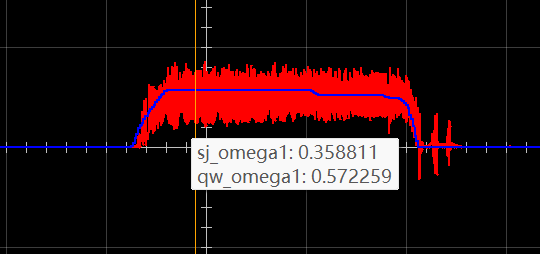
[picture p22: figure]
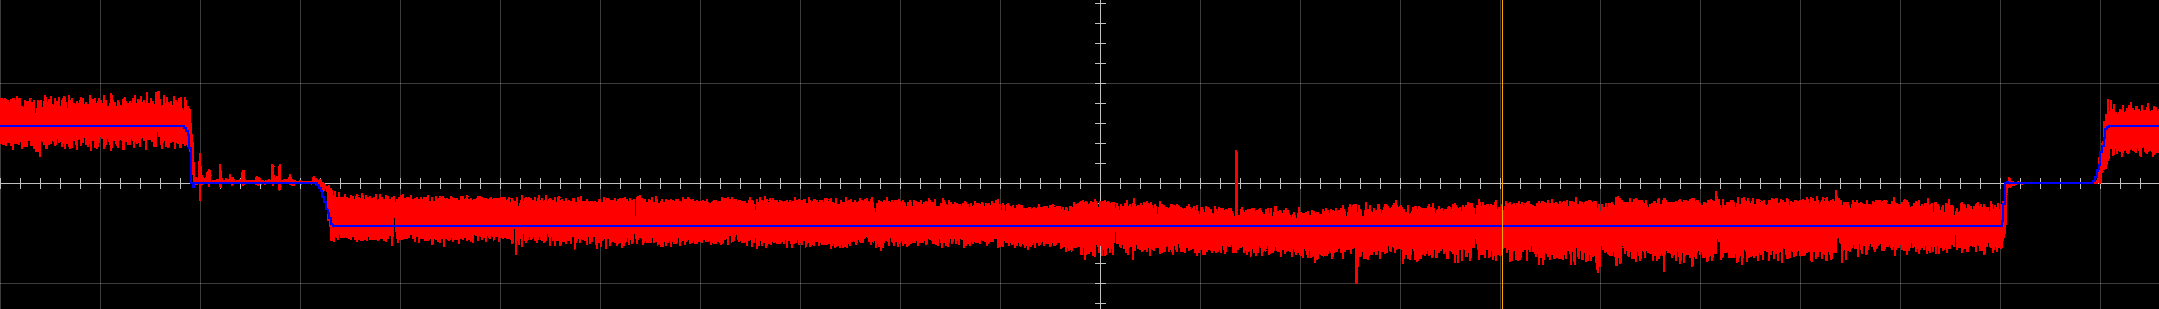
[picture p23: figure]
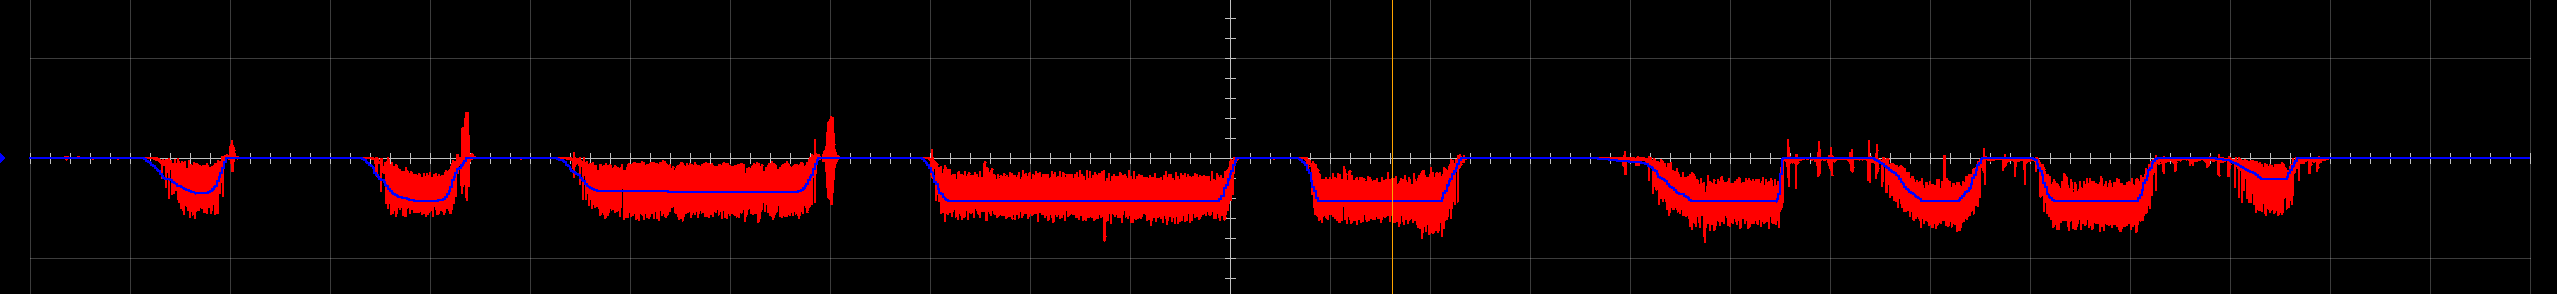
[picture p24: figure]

可见机械臂在运动过程中存在显著的高频震颤，这将对无人机的飞行产生极大威胁。

初步的滤波思路如下：通过二阶低通滤波器对位置信息进行滤波减小重力补偿精波动，通过二阶低通滤波对电机返回的速度信息进行滤波减小速度对力矩输出值的计算波动，但是试验后发现，由于对速度使用了二阶低通滤波器，滤波后的速度相位总是落后于实际速度，导致机械臂冲过头或刹过头，因此产生较大震颤（如下图所示蓝线为原始速度线，红线为过滤后的速度线）

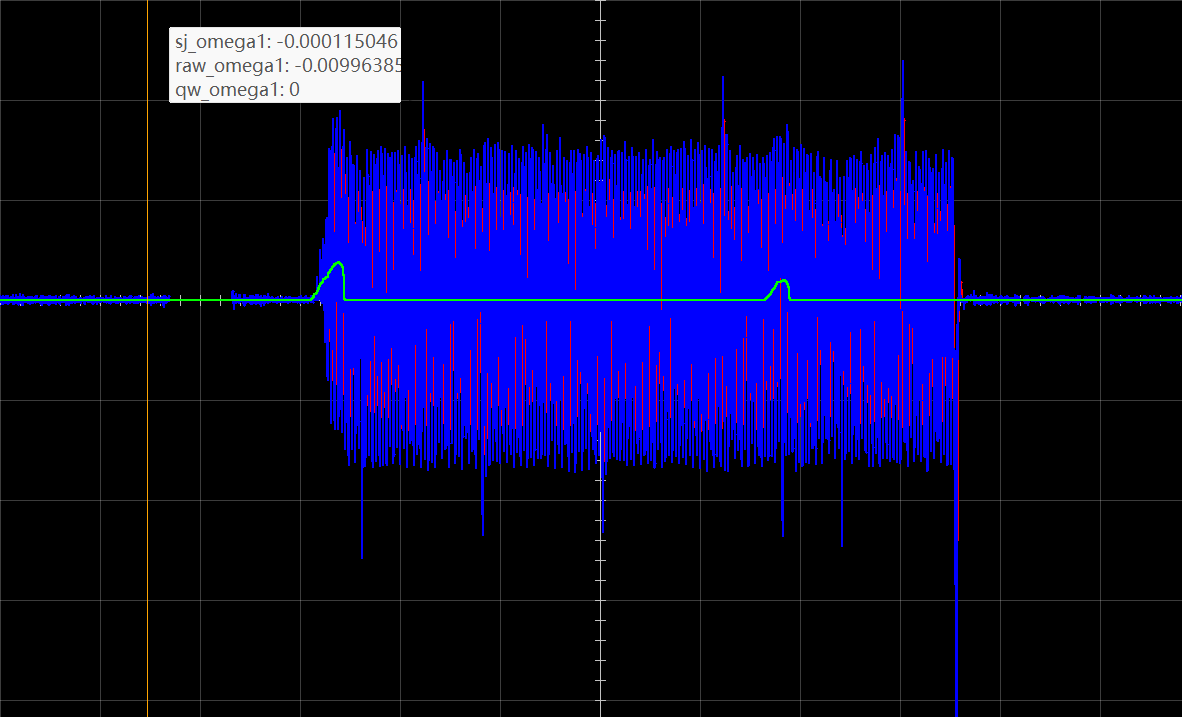
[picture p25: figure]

改进后的思路如下：通过对位置进行二阶低通滤波除去高频噪声，对位置进行差分运算得到速度，通过此速度计算力矩。由于差分dt=0.001s，差分后相当于噪声放大1000倍，极其微小的信号都能引起速度的震颤，若压低位置滤波器的截止频率则会产生相位落后过多，同样引起震颤。（如下图所示，绿线为速度线）

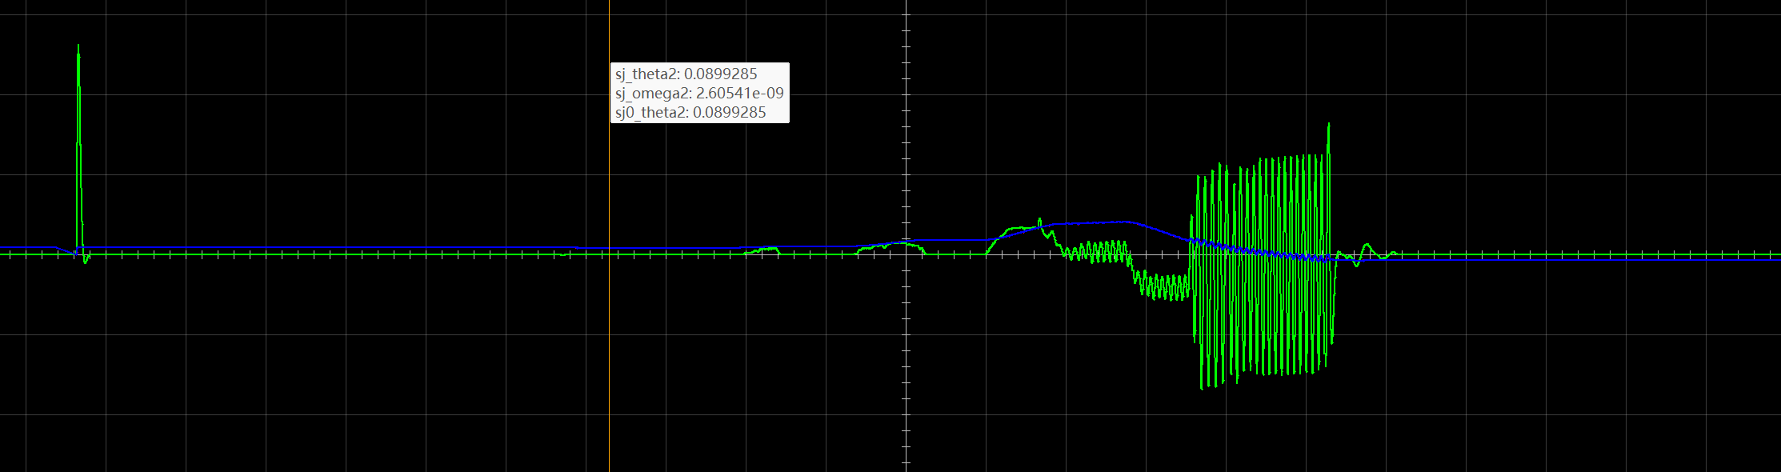
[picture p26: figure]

再次改进的思路如下：由于速度存在震颤，因此对速度再进行一次一阶低通滤波，这样可以排除二阶低通滤波落后过多相位差引起的震颤，补救差分产生的噪声。试验后发现效果并不理想，即使参数达到最优时也存在以下两个问题，第一系统在某些位置存在严重的大幅度震颤，第二系统在运行时产生了低频周期性的震颤。如下图所示（蓝线为原始值，红线为滤波后的值）：

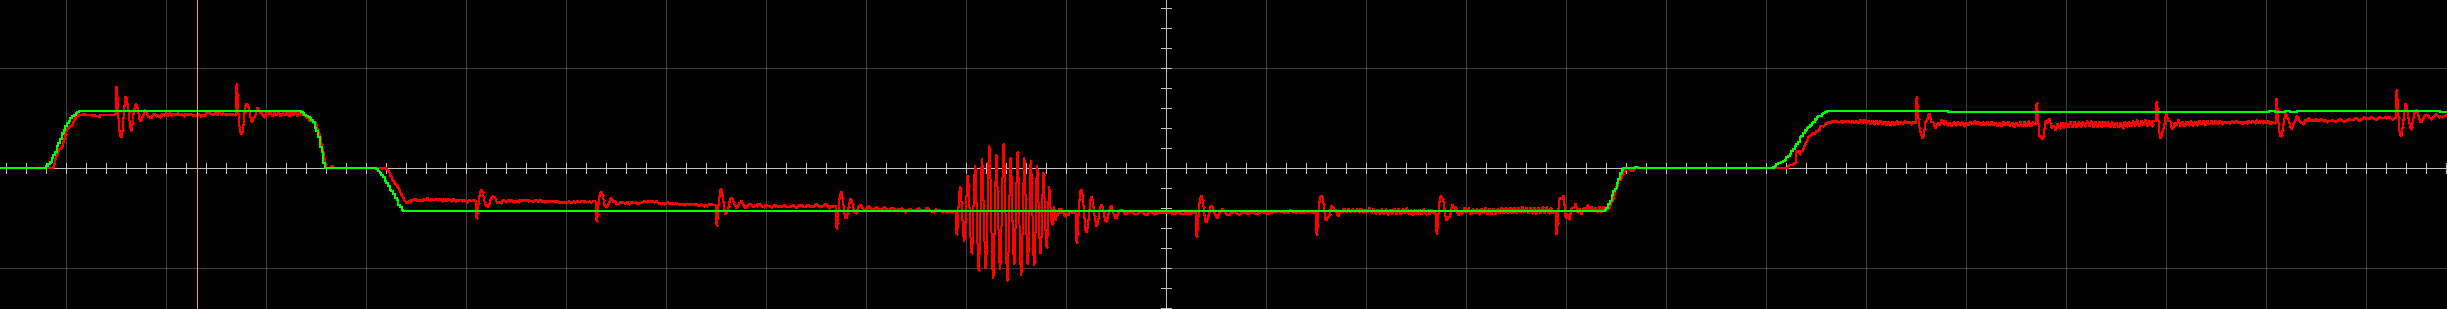
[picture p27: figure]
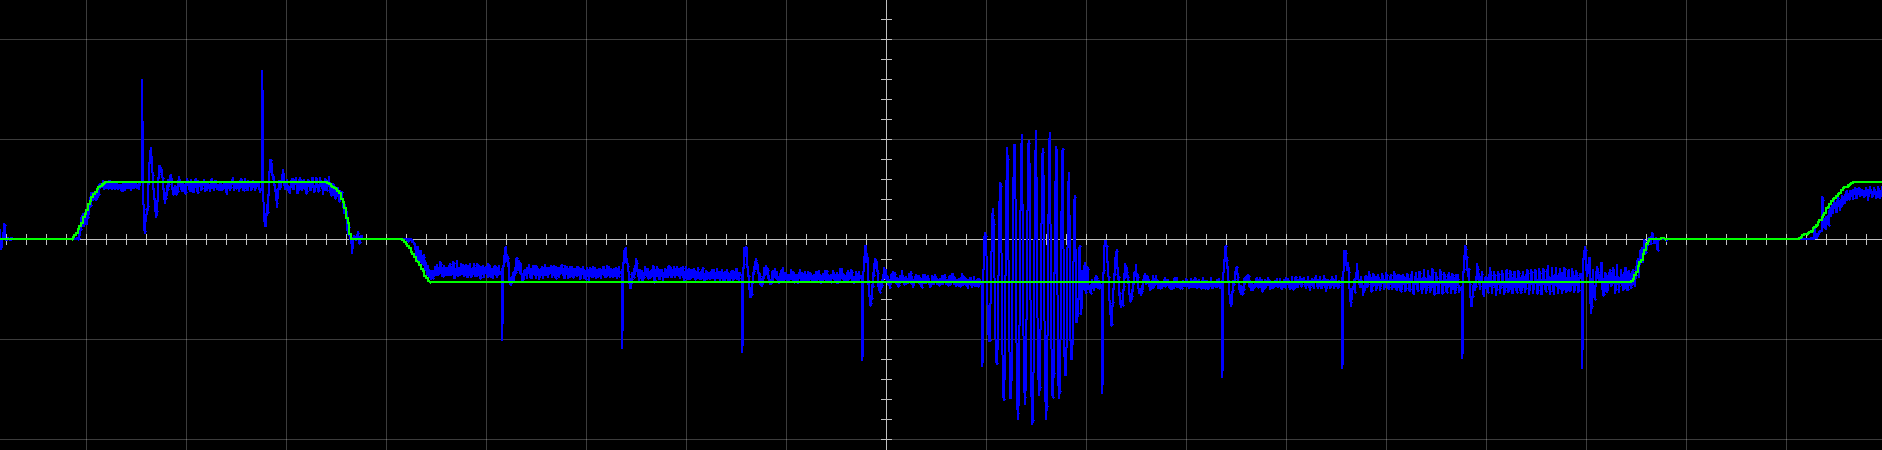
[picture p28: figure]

一阶低通滤波有一定效果但是效果并不最佳，在上述情况下若压低位置环的二阶低通滤波器则会产生相位差引起的大幅震荡，若提高一阶低通滤波器中过滤后速度的占比则也会导致相位差过多引起大幅震荡，若降低参数值则会增多高频小幅震荡，本方法的相位裕度已经到达极限，因此需要转换思路。

通过查询资料获得最终思路，使用微分器将差分与滤波整合。差分是对运动趋势的预测，其具有超前运动的趋势，滤波是对过去信息的使用，具有落后运动的趋势，二者结合可以降低相位差过多产生的大幅震荡，同时也可以实现更好的滤波效果，实现代码如下：

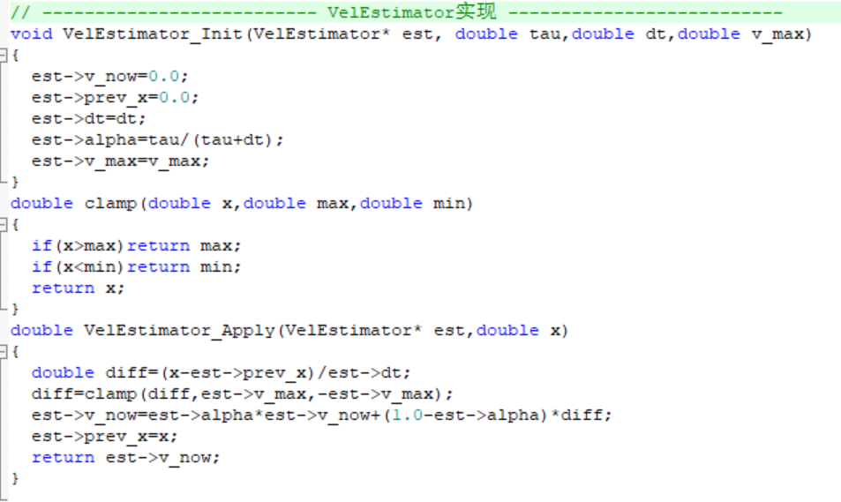
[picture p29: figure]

参数选择：

在该状态下取得了良好的控制效果。速度限幅0.6rad/s，由速度不限幅时的周期性低频震颤幅度测得，周期性震颤如下图所示：

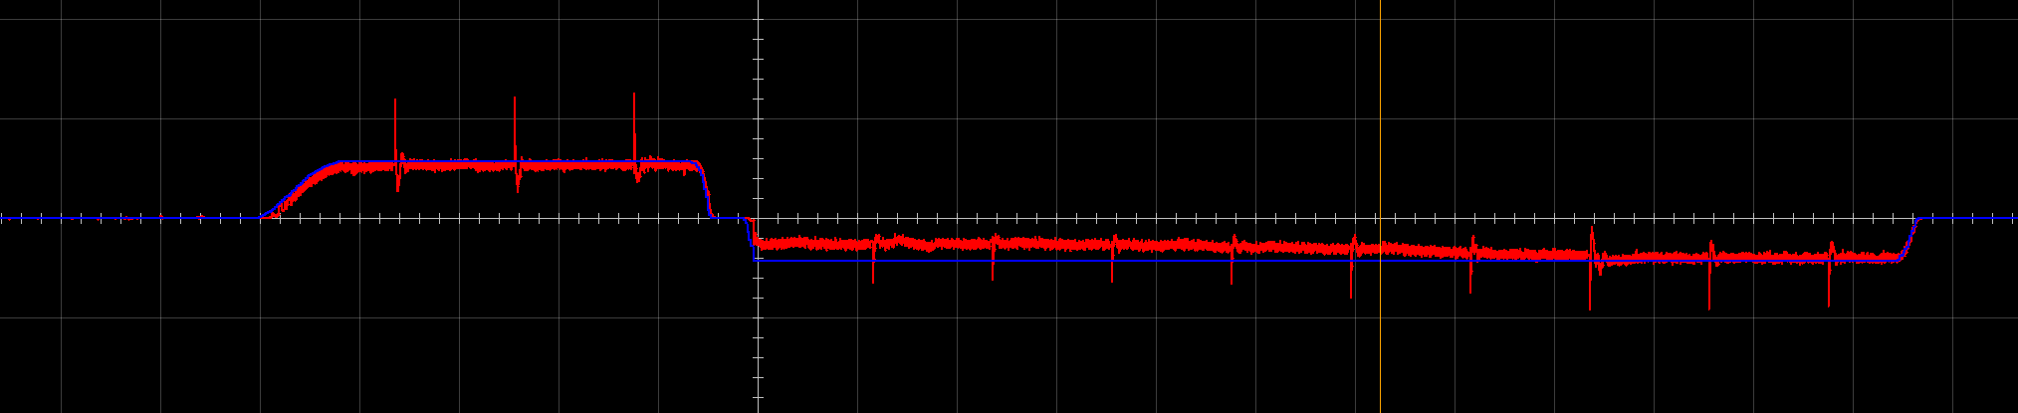
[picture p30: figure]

加入速度限幅后的效果如图：

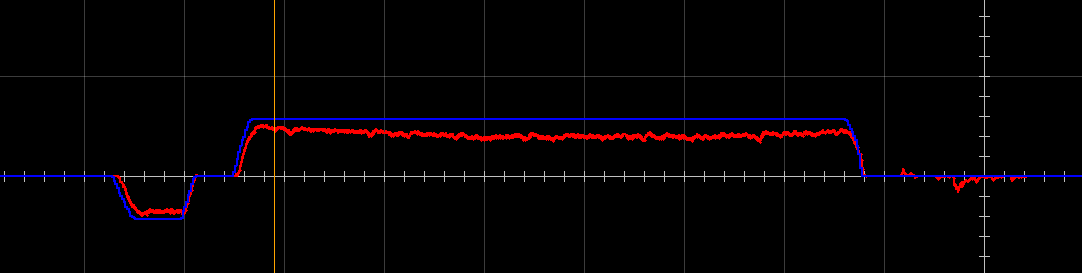
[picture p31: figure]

对比前几种方法，该滤波算法取得了良好的效果，最后通过修正PD参数得到内外杆的期望速度与实际速度关系如下图：

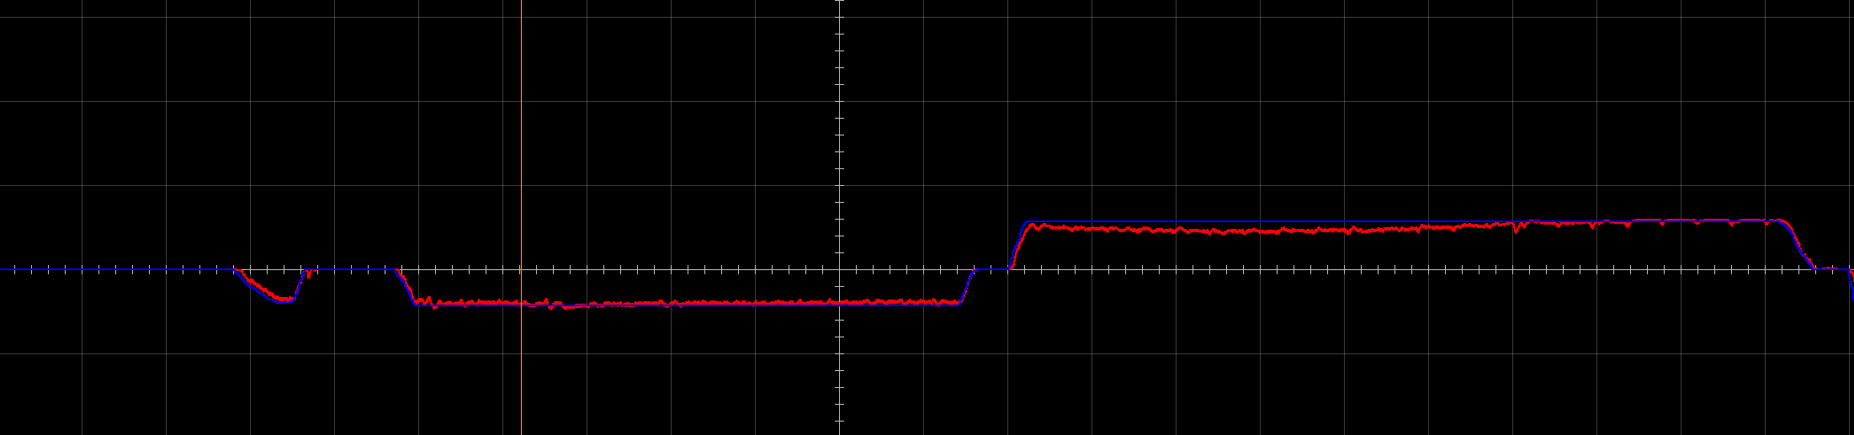
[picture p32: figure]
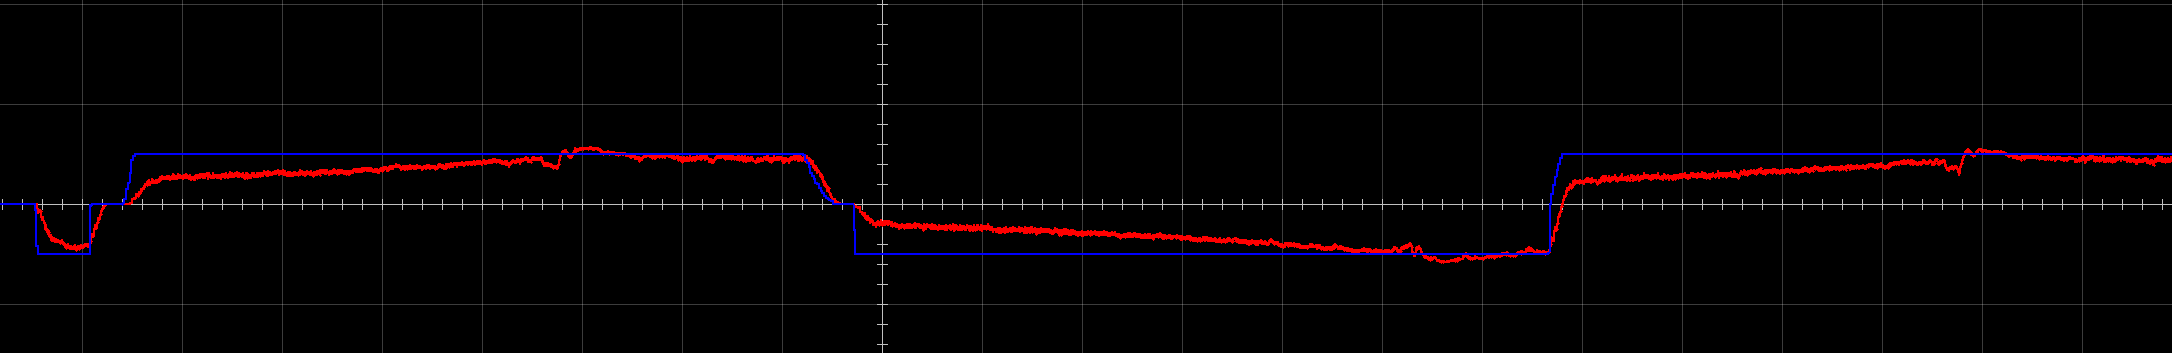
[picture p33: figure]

除调试滤波算法外，本阶段已将遥控器控制代码融入机械臂控制，可以通过遥控器对机械臂进行柔性控制

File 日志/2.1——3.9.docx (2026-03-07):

进入二月份大家相继回家过年，技术方面的更新相对停滞，文书工作正常展开进展顺利。

完成了挑战杯和国创赛的全部文书书写和上交，完成了两篇专利的撰写；分别是《新—松果采摘无人机系统》和《面向松果采摘的视觉系统及使用方法》。

技术方面更新不多，本人作了一些ROS的一些技术学习，尝试了搭建仿真环境，做了一些gazebo仿真和APM固件的使用，烧录了一套八旋翼apm固件到飞控中，并实现了飞控辅助控制云台自稳，这里毕竟是辅助控制自稳，飞控通过SR2_EXTRA1参数设置发送频率（相机手册里面推荐50HZ）发送的是ATTITUDE消息（姿态角）和ATTITUDE_QUATERNION（四元数）然后A8mini的IMU校准算法融合这些数据，补偿零偏、温漂、轴间误差。最终的效果感觉还不错。

这里附上参数速查：

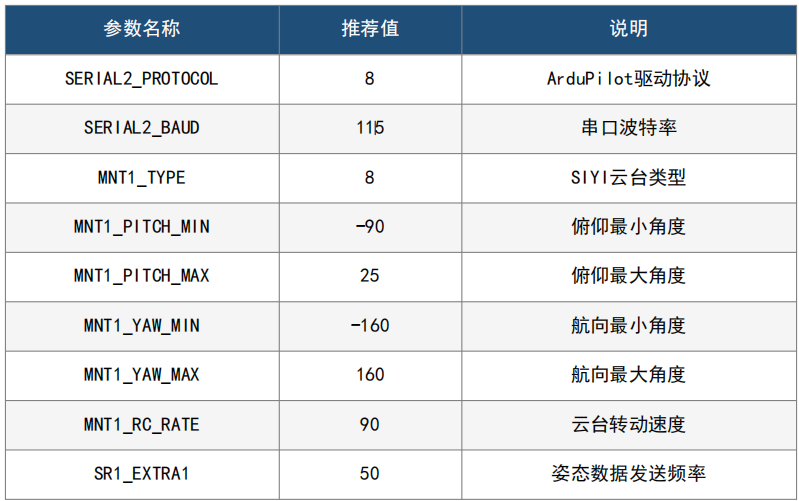
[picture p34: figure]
屏幕截图 2026-03-07 143502

然后招募了三个新同学到我们的团队中，团队在文书和技术能力层面都有较为显著的提升

3.7工作汇报

已经完成的任务：

机载电脑环境配置

完成了所有硬件的通讯和数据传输调节

完成了飞控辅助控制自稳算法

写了一个云台自动录制并保存的脚本书写

完成了两篇专利的书写

较为系统的学习和了解了杨老师的模型，并已经会使用

补全了师兄的结构图，作了激光雷达和云台相机的结构

规划：

开学两周内完成一个视觉模型的训练和部署，集成一下飞控、机载电脑、云台相机

预计部署激光雷达开源SLAM算法，作为避障使用

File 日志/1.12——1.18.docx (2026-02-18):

1.12——1.18工作总结

关于电源：机载电脑使用19V直流供电，云台相机在不改线的情况下使用3s-6s动力电池供电，xt30接口，激光雷达一样使用xt30接口供电，电压范围比较大，应该不太用考虑，但是证明二者都需要独立供电，或者绘制分压（流）板，或者干脆采用一拖二改线。

关于机载电脑：使用英伟达开发的jetpack系列Linux系统，系统是在Ubuntu20.04和22.04基础上进行的适配和升级，连接显示器的接口是较为特殊的displayport（DP）接口，需要一个其与HDMI的转接线配合使用，接口如下图：

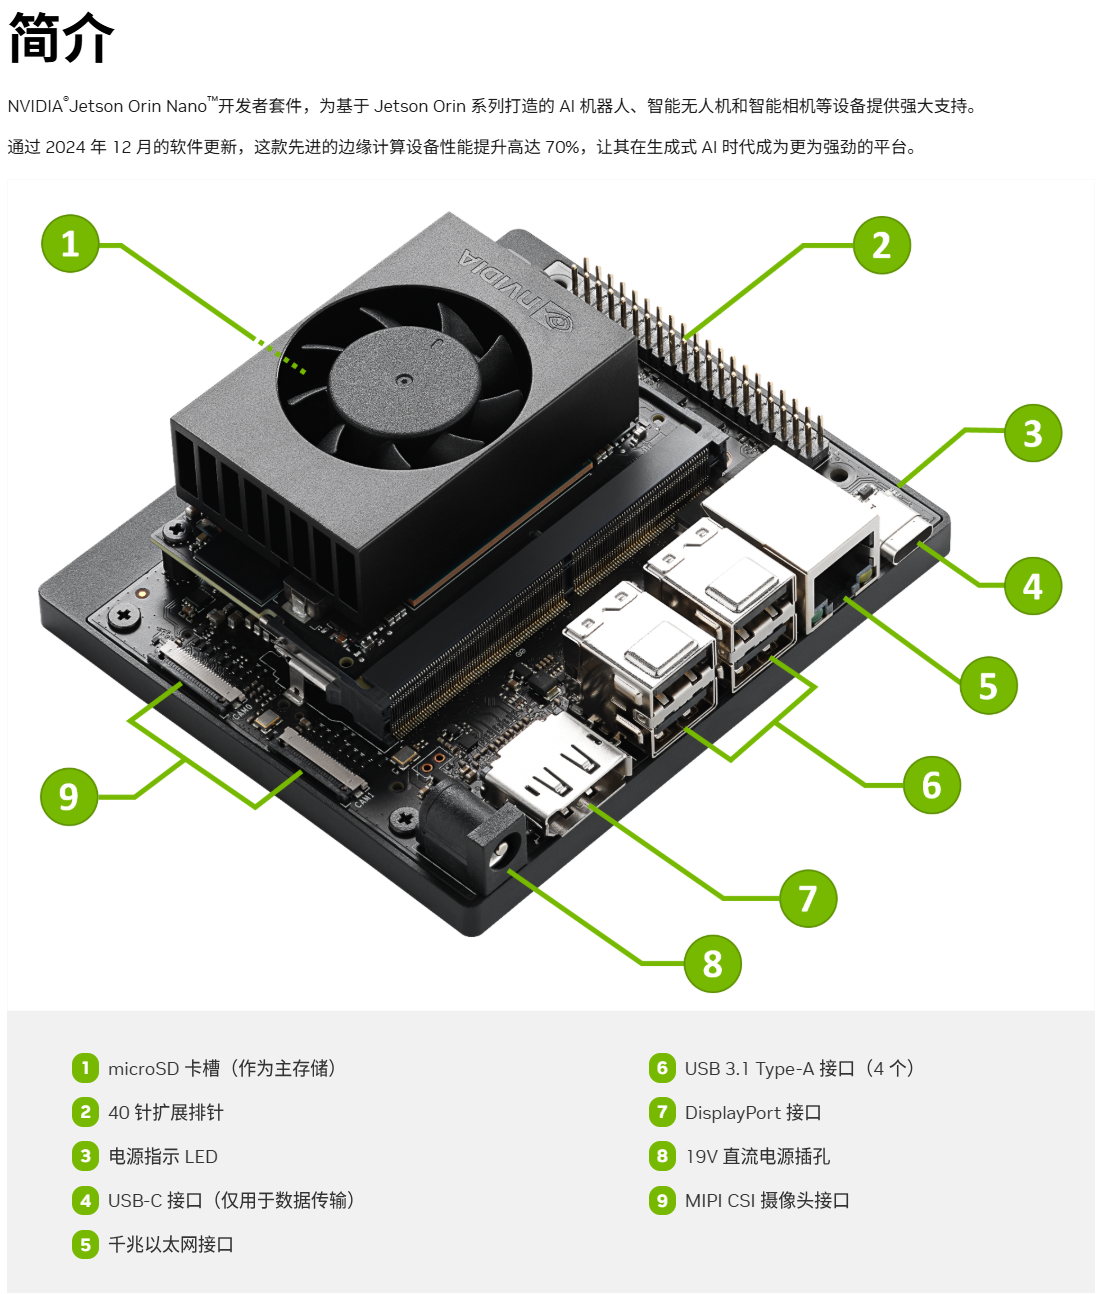
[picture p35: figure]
屏幕截图 2026-01-16 183940

系统镜像烧录方法分为microSD卡烧录和用官方提供的SDK Manager烧录，可以提前加装好的固态硬盘（最多两条）来替代SD卡，我们配置了两台机载电脑，一个用的是64G的SD卡，另一个用了一条128G固态硬盘，后续对比性能再对区别下结论。SDK Manager要用linux系统启动，可以用虚拟机也可以用双系统，这里面比较离谱的是如果先打开虚拟机再连接板子，虚拟机会识别不到板子，顺序反过来就行了（乐）。双系统（我用的是20.04）没有问题。

顺带提一下我的20.04双系统一直连不上网，只能手机USB共享网络，这个属于乌邦图的历史遗留问题，目前好像除了换网卡没有太好的解决办法（我的电脑是Y7000P，按照CSDN的说法这一代的网卡最恶心），遂不解决了。

前期烧录系统遇到重大困难，主要是官方技术文档有点（实则不是有点）混乱，nano技术文档里面的镜像是jetpet7.系列，后续了解才知道它只适配tour系列板子，后续重新找镜像，但是总是失败，系统能够启动，但是会卡在第一个界面，然后就黑屏，1.17日换了更老的jetpet版本尝试烧录，一直尝试到凌晨两点还是没有成功，次日（今天）11点我们重新开始使用SDKmanager尝试，今天动力电池应该就能到，我们可以在另一个板子上调一下激光雷达，另一个板子系统有了，但是环境现在配置的不是特别好，所以今天能到哪一步还不确定。

云台相机图传功能占用机载电脑一个以太网口，云台的控制既可以用机载电脑也可以用飞控，用飞控的话占用一个S.Bus输出，用机载电脑可以无需额外接线，jetson通过UDP协议像相机发送控制命令。激光雷达也占用以太网口，后续协同使用应该需要拓展坞。

唯一一个不需要额外硬件的是深度相机，目前在本地运行正常，从图像数据的类型和结果来看，这个相机确实适用抵近拍摄识别，这里附上一张实时图传的图片，因为点云图传的参数看不懂，随便调了一版，后续学习后再调一下。

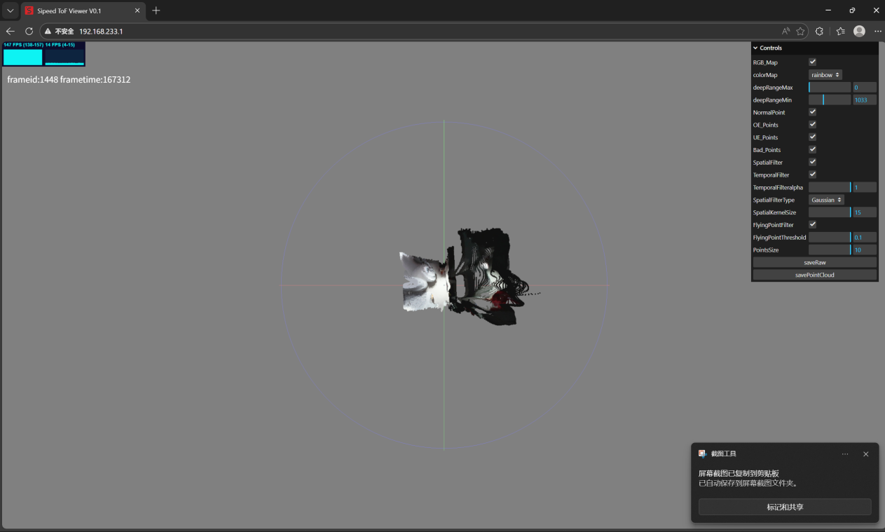
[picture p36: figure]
屏幕截图 2026-01-17 221705

硬件方面大概就是这些进度，其实感觉没啥太好的进度（乐），初期配环境还是太痛苦了

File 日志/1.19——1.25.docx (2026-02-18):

1.19——1.25工作总结

机载电脑：我们使用独立于SDK Manager和SD卡的烧录方法成功烧录使用固态硬盘了jetpet35.X镜像，此种方法要使用虚拟机。jetpet系统在≤35.X的版本中是Ubuntu20,04的改进版本，所以会带来一定的版本问题，例如无法安装ROS2 humble。同时，经过我们的计算和实践，固态硬盘烧录方法是一个稳定 且成功率高的方法。我们使用的固态是128G，然而经过查阅资料，官方系统约占用53G（含有CUDA等SDK），NVIDIA Isaac ROS约54G，所以为了后续开发的方便，建议使用256G的。

深度相机在linux系统的运行前期出现巨大问题，原因是这款相机同时拥有USB2.0通讯和USB创建虚拟网口通信两种数据传输形式，如图：

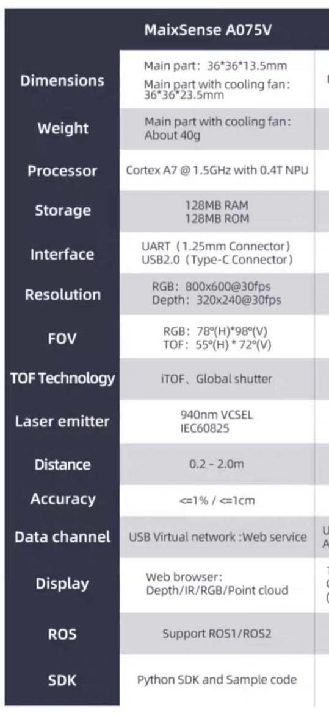
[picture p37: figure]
0153a4bb069afb1c71fea452422465d7
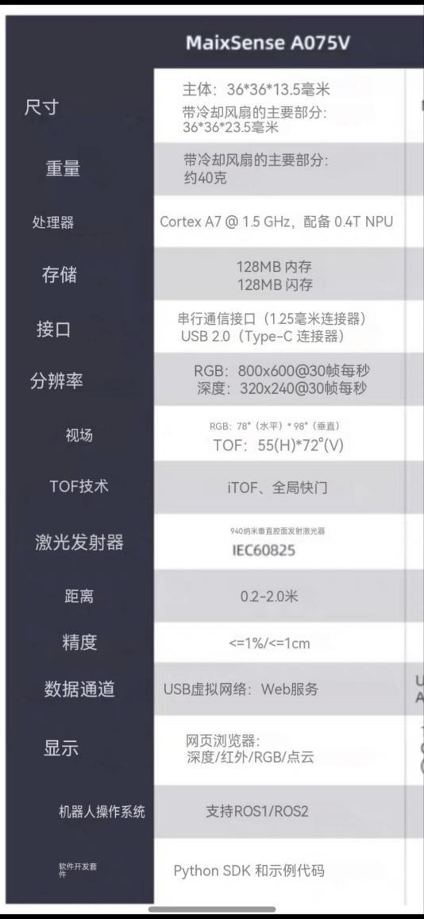
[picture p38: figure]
41a42e1e674289fb6faff32096597655

一方面，对于上位机，jetson总把虚拟网口识别成实际网线连接产生的网口，又由于linux系统对于有线连接网络存在优先级，网络的连接总是在WIFI和网口中反复横跳，影响使用和数据传输，解决方法如下：

首先，创建并编辑一个udev下针对深度相机的规则文件：

sudo vi /etc/udev/rules.d/depth-camera-net.rules //创建一个叫depth-camera-net.rules的文件并用vi编辑，编辑内容为：

SUBSYSTEM==”net”,ACTION==”add”,ATTRS{idVendor}==”0525”,ATTRS{idProduct}==”a4a2”,NAME=”depthcamera”

以上规则的含义是：识别ID为0525:a2a4的设备，并将其连接的接口名强制改为depthcamera

然后，创建一个配置文件来忽略该设备：

sudo vi /etc/NetworkManager/conf.d/99-unmanaged-depth-camera.conf

编辑配置文件内容为：

[keyfile]

unmanaged-devices=depthcamera

另一方面，当连接USB时深度相机不稳定，具体表现为：高频重复运行lsusb（或ip addr show）会发现板子有时能识别到相机，有时则不行，这直接导致了无法给接口分配ip地址，进而无法ping通，解决方法如下：

首先，通过typec口连接深度相机，然后依次运行以下命令行：

#1.启动depthcamera接口

sudo ip link set depthcamera up

#2.检查状态

ip link show depthcamera

#应该显示:state UP

#3.分配IP地址

sudo ip addr add 192.168.233.2/24 dev depthcamera

#4.验证配置

ip addr show depthcamera

# 应该显示:inet 192.168.233.2/24

之后ping一下看看是否能ping通，如果能ping通，就大功告成，建图效果如下：

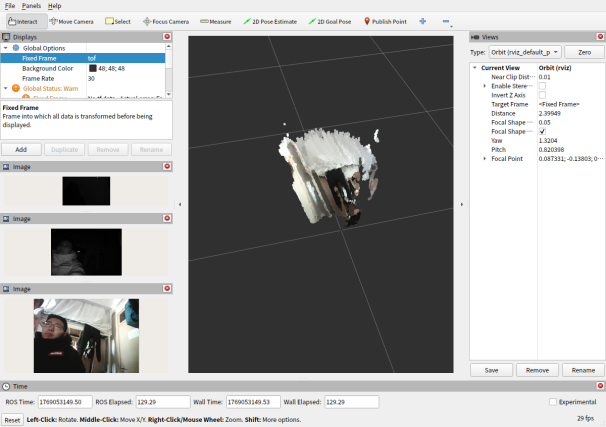
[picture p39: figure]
d6dc5c7c8bfd5c9324f1eed6b9157c8e
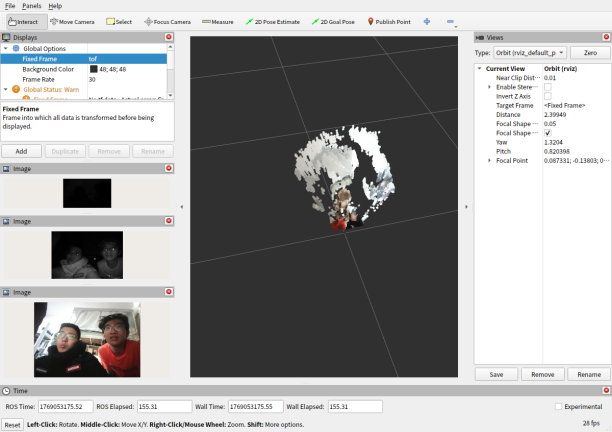
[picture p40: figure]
abb1542ad4fff40748ebf02cfeb04269

一个典型的RGB-D数据包含：

- RGB图像：标准的3通道彩色图像，格式为H×W×3

- 深度图：单通道图像，格式为H×W，每个像素值为浮点数

这些都可以被OpenCV读取。

1.23凌晨之前调试好使的板子出现了异常无法进入系统，可能是关机不规范的原因，只好重新烧录。

由于我们没有能读取固态硬盘的读卡器，遂采用自身带有擦除功能的烧录方式SDK Manager，使用SDK Manager依然需要使用虚拟机（在一本书上面看到的教程），原因是需要两次点击连接设备，如图：

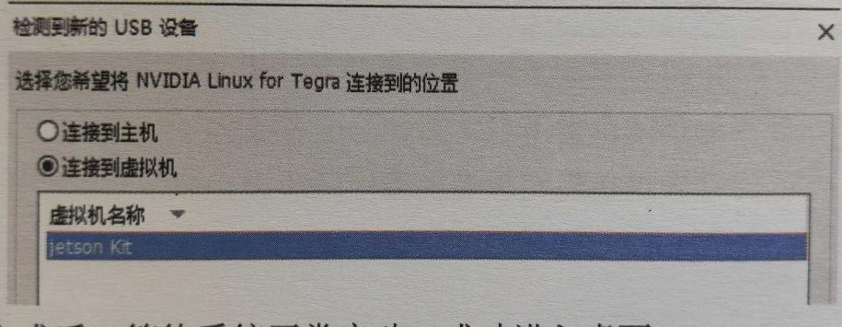
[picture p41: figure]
8ffe0e2b2d47ea27d7bdbd7ad57ff50a

这次烧录的比较顺畅，结论是先前的SD卡容量不够，换成更大的固态硬盘就好多了。

这次我们配置了jetpet6.X系列，这个系列支持ROS2 humble，为以后开发提供更新的版本。

同时，另一台板子在运行激光雷达相对顺畅，基础驱动的安装按照官方提供的文档如下：

git clone https://github.com/Livox-SDK/Livox-SDK2.git

git clone https://github.com/Livox-SDK/livox_ros_driver2.git ws_livox/src/livox_ros_driver2

后续教程：

https://blog.csdn.net/longwenht/article/details/151714218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

官方驱动同时支持ROS和ROS2，不需要额外配置，所以比较友善，唯一的问题就是连接github不是特别稳定，这个多试几次就好了，或者可以尝试在Linux里面下梯子，激光雷达建图如下：

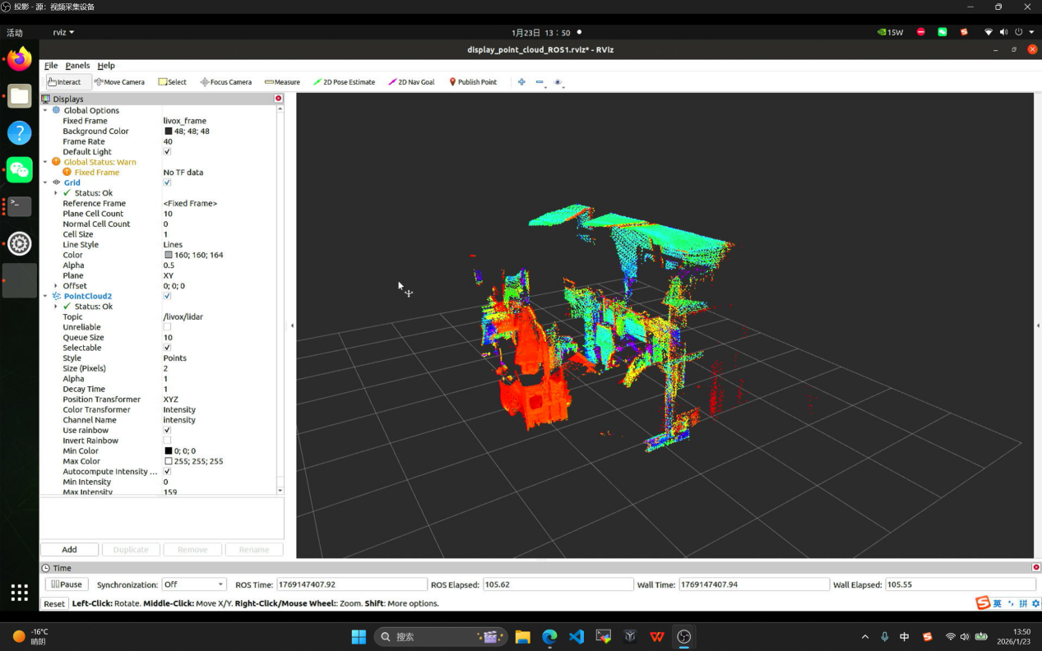
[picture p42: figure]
屏幕截图 2026-01-23 135012

移动激光雷达能看到更多的点云图

从云台相机的参数来看，这款相机支持多种数据传输方式，自稳即可以连接飞控，也可以连接机载电脑用算法控制，开发自由度相当可观。

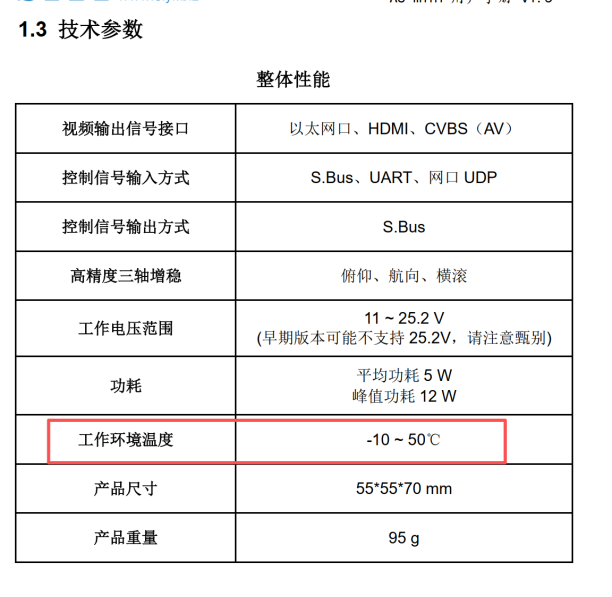
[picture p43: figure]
fd0050c989ada0ae2dc0e988cc51aaa4

注意了一下工作温度，而且这个相机的散热性能好像一般，但是问题不大。

云台相机的通讯也依赖以太网口，我们尝试用FFmpeg拉取视频流看一下图传是否正常，并用官方技术手册里面的自检代码测试了一下云台自稳：

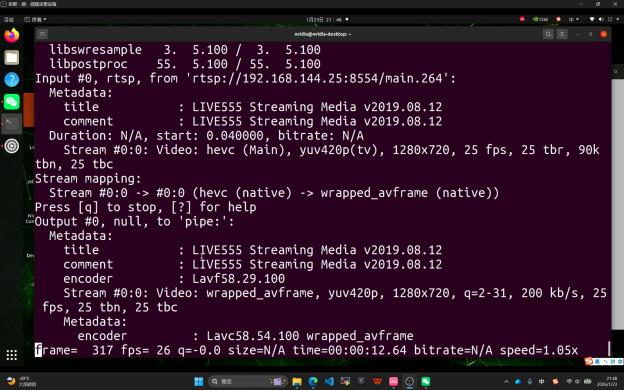
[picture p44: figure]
屏幕截图 2026-01-23 214811
屏幕截图 2026-01-23 215930

可以看到相机能以十六进制数据正常输出姿态信息，我们手动也试了一下自稳定，效果一般，应该是没接入飞控或者是没加算法的原因。

相机支持4K图像传输，图像相当清晰：

屏幕截图 2026-01-23 222410

提前提交了一周的工作日志，这一个阶段主要攻克了烧录问题（多次失败总结于是对高性能开发板使用的陌生）、各个组件的通讯和硬件需求，以及各个组件前期的配置（网关、静态IP）总体相对顺畅，下一个阶段我们想针对于激光雷达了解一些建图算法并尝试一下部署，队里面同学在二月初要打美赛，然后基本上也就要回家了，后续工作还没有想好怎么继续展开。
